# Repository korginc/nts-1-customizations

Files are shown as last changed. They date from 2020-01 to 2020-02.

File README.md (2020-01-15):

# nts-1-customizations

Official repository for hardware customizations of the [Nu:Tekt NTS-1 digital kit](https://www.korg.com/nts_1) programmable synthesizer. 

Make your own custom interface using reference schematics, CAD and PCB data, and libraries for the Arduino IDE.

## Repo Content

* _Arduino/package_nts1_custom_panels_index.json_: Arduino IDE package Boards Manager package description file
* _Custom_Panel_RevC/_: Content specific to NTS-1 Custom Panel reference board revision C
  * _Arduino/libraries/_: Arduino IDE libraries
  * _Gerber/_: Raw PCB Gerber data output
  * _KiCAD/_: [KiCAD](https://kicad-pcb.org/) project
  * _BOM-mouser.pdf_: Bill of materials with [Mouser](https://www.mouser.com/) part numbers in PDF format
  * _BOM-mouser.xls_: Bill of materials with [Mouser](https://www.mouser.com/) part numbers in XLS format (can be uploaded directly to cart)
  * _Gerber\_reference.pdf_: PCB trace and masks visual reference in PDF format
  * _mount\_diagram.pdf_: Part placement visual reference in PDF format
  * _schematic.pdf_: Circuit diagram in PDF format

## Assembly/Programming

Refer to the [companion web site](https://korginc.github.io/nts-1-customizations) for assembly/programming instructions, examples and further reference.

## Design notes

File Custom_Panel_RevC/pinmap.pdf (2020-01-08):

NTS-1 Custom Panel

Arduino IDE pin mapping

| CN7 outside | | CN7 inside | | CN10 inside | | CN10 outside
pin | STM32 | arduino | pin | STM32 | arduino | pin | STM32 | arduino | pin | STM32 | arduino
1 | PC_10 | D16 | 2 | PC_11 | D31 | 1 | PC_9 | D33 | 2 | PC_8 | D34
3 | PC_12 | D17 | 4 | PD_2 | D32 | 3 | PB_8 | D15/I2C SCL | 4 | PC_6 | D35
5 | 3.3V | | 6 | x | | 5 | PB_9 | D14/I2C SDA | 6 | PC_5 | D36/A12
7 | BOOT0 | | 8 | GND | | 7 | 3.3Vref | | 8 | x
9 | PF_6 | D18 | 10 | x | | 9 | GND | | 10 | x
11 | PF_7 | D19 | 12 | 3.3V | | 11 | PA_5 | D13/A9/SPI SCK | 12 | PA_12 | D37
13 | PA_13 | D20 (used for SWD) | 14 | NRST | | 13 | PA_6 | D12/A8/SPI MISO | 14 | PA_11 | D38
15 | PA_14 | D21 (used for SWD) | 16 | 3.3V | | 15 | PA_7 | D11/A7/SPI MOSI | 16 | PB_12 | D39 (used for NTS-1)
17 | PA_15 | D22 | 18 | x | | 17 | PB_6 | D10 | 18 | PB_11 | D40
19 | GND | | 20 | GND | | 19 | PC_7 | D9 | 20 | GND
21 | PB_7 | D23 | 22 | GND | | 21 | PA_9 | D8 | 22 | PB_2 | D41
23 | PC_13 | D24 | 24 | x | | 23 | PA_8 | D7 | 24 | PB_1 | D42/A6
25 | PC_14 | D25 | 26 | x | | 25 | PB_10 | D6 | 26 | PB_15 | D43 (used for NTS-1)
27 | PC_15 | D26 | 28 | PA_0 | D49/A0 | 27 | PB_4 | D5 | 28 | PB_14 | D44 (used for NTS-1)
29 | PF_0 | D27 | 30 | PA_1 | D50/A1 | 29 | PB_5 | D4 | 30 | PB_13 | D45 (used for NTS-1)
31 | PF_1 | D28 | 32 | PA_4 | D51/A2 | 31 | PB_3 | D3 | 32 | x
33 | 3.3V | | 34 | PB_0 | D52/A3 | 33 | PA_10 | D2 | 34 | PC_4 | D46/A13
35 | PC_2 | D29/A10 | 36 | PC_1 | D53/A4 | 35 | PA_2 | D1/TX(used for CN3) | 36 | PF_5 | D47
37 | PC_3 | D30/A11 | 38 | PC_0 | D54/A5 | 37 | PA_3 | D0/RX(used for CN3) | 38 | PF_4 | D48

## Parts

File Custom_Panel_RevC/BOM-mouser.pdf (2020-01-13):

Mfr Part Number (Input) | Manufacturer Part Number | Mouser Part Number | Manufacturer Name | Description | Quantity 1 | Datasheet URL | Unit Price
RC0603JR-070RL | RC0603JR-070RL | 603-RC0603JR-070RL | Yageo | Thick Film Resistors - SMD Thick Film Resistors - SMD ZERO OHM JUMPER | 1 | https://www.mouser.com/datasheet/2/447/PYu-RC_Group_51_RoHS_L_10-1664068.pdf | $0.10
RC0603JR-0733RL | RC0603JR-0733RL | 603-RC0603JR-0733RL | Yageo | Thick Film Resistors - SMD Thick Film Resistors - SMD 33 OHM 5% | 1 | https://www.mouser.com/datasheet/2/447/PYu-RC_Group_51_RoHS_L_10-1664068.pdf | $0.10
RC0603JR-0747RL | RC0603JR-0747RL | 603-RC0603JR-0747RL | Yageo | Thick Film Resistors - SMD Thick Film Resistors - SMD 47 OHM 5% | 4 | https://www.mouser.com/datasheet/2/447/PYu-RC_Group_51_RoHS_L_10-1664068.pdf | $0.10
RC0603JR-07220RL | RC0603JR-07220RL | 603-RC0603JR-07220RL | Yageo | Thick Film Resistors - SMD Thick Film Resistors - SMD 220 OHM 5% | 8 | https://www.mouser.com/datasheet/2/447/PYu-RC_Group_51_RoHS_L_10-1664068.pdf | $0.10
RC0603JR-07100KL | RC0603JR-07100KL | 603-RC0603JR-07100KL | Yageo | Thick Film Resistors - SMD Thick Film Resistors - SMD 100K OHM 5% | 1 | https://www.mouser.com/datasheet/2/447/PYu-RC_Group_51_RoHS_L_10-1664068.pdf | $0.10
RC0603JR-0710KL | RC0603JR-0710KL | 603-RC0603JR-0710KL | Yageo | Thick Film Resistors - SMD Thick Film Resistors - SMD 10K OHM 5% | 4 | https://www.mouser.com/datasheet/2/447/PYu-RC_Group_51_RoHS_L_10-1664068.pdf | $0.10
RC0603JR-071KL | RC0603JR-071KL | 603-RC0603JR-071KL | Yageo | Thick Film Resistors - SMD Thick Film Resistors - SMD 1K OHM 5% | 2 | https://www.mouser.com/datasheet/2/447/PYu-RC_Group_51_RoHS_L_10-1664068.pdf | $0.10
RC0603JR-0747KL | RC0603JR-0747KL | 603-RC0603JR-0747KL | Yageo | Thick Film Resistors - SMD Thick Film Resistors - SMD 47K OHM 5% | 1 | https://www.mouser.com/datasheet/2/447/PYu-RC_Group_51_RoHS_L_10-1664068.pdf | $0.10
C0603C104K4REC | C0603C104K4RECTU | 80-C0603C104K4RECTU | KEMET | Multilayer Ceramic Capacitors MLCC - SMD/SMT Multilayer Ceramic Capacitors MLCC - SMD/SMT 16V 0.1uF 0603 X7R 10% | 4 | https://www.mouser.com/datasheet/2/212/KEM_C1090_X7R_ESD-1103328.pdf | $0.11
C0603C102K4REC | C0603C102K4RECAUTO | 80-C0603C102K4RECAUT | KEMET | Multilayer Ceramic Capacitors MLCC - SMD/SMT Multilayer Ceramic Capacitors MLCC - SMD/SMT 16V 1000pF 0603 X7R 10% AEC-Q200 | 2 | https://www.mouser.com/datasheet/2/212/KEM_C1090_X7R_ESD-1103328.pdf | $0.15
C0805C105K4PAC | C0805C105K4PAC | 80-C0805C105K4PAC | KEMET | Multilayer Ceramic Capacitors MLCC - SMD/SMT Multilayer Ceramic Capacitors MLCC - SMD/SMT 16V 1uF X5R 0805 10% | 1 | https://www.mouser.com/datasheet/2/212/KEM_C1006_X5R_SMD-1103249.pdf | $1.05
1-87215-9 | 1-87215-9 | 571-1-87215-9 | TE Connectivity | Headers & Wire Housings Headers & Wire Housings 38 MODII HDR DRST UNSHRD .100 | 2 | https://www.mouser.com/datasheet/2/418/NG_CD_87215_J4-642383.pdf | $13.56
215299-0 | 215299-2 | 571-215299-2 | TE Connectivity | Headers & Wire Housings Headers & Wire Housings 1X02P RCPT HV-100 TE | 1 | https://www.mouser.com/datasheet/2/418/NG_CD_215299_E-1247332.pdf | $0.64
215299-6 | 215299-6 | 571-215299-6 | TE Connectivity | Headers & Wire Housings Headers & Wire Housings 6P RECPT VERT HV-100 | 1 | https://www.mouser.com/datasheet/2/418/NG_CD_215299_E-1247285.pdf | $1.16
215299-8 | 215299-8 | 571-215299-8 | TE Connectivity | Headers & Wire Housings Headers & Wire Housings 8P RECPT VERT HV-100 | 2 | https://www.mouser.com/datasheet/2/418/NG_CD_215299_E-1247329.pdf | $1.45
826926-3 | 826926-3 | 571-826926-3 | TE Connectivity | Headers & Wire Housings Headers & Wire Housings 1X03 POS VERT TIN | 2 | https://www.mouser.com/datasheet/2/418/NG_CD_826629_AC-1262378.pdf | $0.27
826926-4 | 826926-4 | 571-826926-4 | TE Connectivity | Headers & Wire Housings Headers & Wire Housings 1X04 POS VERT TIN | 1 | https://www.mouser.com/datasheet/2/418/NG_CD_826629_AC-673695.pdf | $0.32
XJ8B-0711 | XJ8B-0211 | 653-XJ8B-0211 | Omron | Headers & Wire Housings Headers & Wire Housings Sensor I/O Connector | 2 | https://www.mouser.com/datasheet/2/307/en-xg8-1539045.pdf | $0.39
WP7113SRD/J4 | WP7113SRD/J4 | 604-WP7113SRDJ4 | Kingbright | Standard LEDs - Through Hole Standard LEDs - Through Hole 5mm Red LED 640nm | 8 | https://www.mouser.com/datasheet/2/216/WP7113SRD-J4-1114353.pdf | $0.56
RK09K1130A5R | RK09K1130A5R | 688-RK09K1130A5R | ALPS | Potentiometers Potentiometers 10 KOhms 20% | 1 | https://www.mouser.com/catalog/specsheets/alps_alps-s-a0003696969-1.pdf | $0.84
SKRGAAD010 | SKRGAAD010 | 688-SKRGAAD010 | ALPS | Tactile Switches Tactile Switches RND 6.0x4.3mm 100gf | 10 | https://www.mouser.com/catalog/specsheets/alps_alps-s-a0002902225-1.pdf | $0.21
STM32F030R8T6 | STM32F030R8T6 | 511-STM32F030R8T6 | STMicroelectronics | ARM Microcontrollers - MCU ARM Microcontrollers - MCU Value-Line ARM MCU 64kB 48 MHz | 1 | https://www.mouser.com/datasheet/2/389/stm32f030f4-956260.pdf | $1.89
827914-3 | 827914-3 | 571-827914-3 | TE Connectivity | Headers & Wire Housings Headers & Wire Housings 2 POS POST SHUNT | 1 | https://www.mouser.com/datasheet/2/418/NG_SS_108-37006_D-876462.pdf | $0.43

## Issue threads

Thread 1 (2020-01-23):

NTS-1_CustomPanel.lib is missing

tokuhira, 2020-01-23:
**Is your feature request related to a problem? Please describe.**
"Custom_Panel_RevC / KiCAD / sym-lib-table" refers to "$ {KIPRJMOD} /NTS-1_CustomPanel.lib", but it is not included in the repository.

**Describe the solution you'd like**
Having a symbol table can be very helpful when we try to further customize the board. If it is publicly available, add it to the repository.

 Anyway, thank you very much for the great project. This is the best introduction to making electronic instruments ever.

grajohnt, 2020-02-02:
Echoing this. It would be great to start making modifications, but without these symbols, it's a bit tricky to even get started.

KreoPensas, 2021-11-22:
Still nothing?

fopinski, 2023-02-02:
Push... Would be a shame. Maybe that's why we cannot find custom pannels at all?

matozoid, 2023-02-11:
Since this repository was made, nothing happened. No code was added, no issues were addressed, it is completely abandoned. Maybe someone within Korg can be contacted directly about this.

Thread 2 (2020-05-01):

A Simple Introduction Please

scotus-49, 2020-05-01:
Do you have anywhere information for the average Arduino user to get started with customizing the NTS-1? Something using readily available components for simple experiments? Your examples seem to assume a high professional level of soldering and programming.

Has anyone outside of Korg actually done this? I can at present find no sign on the internet of anyone managing to do any hardware customization. It"s a great idea, but how does the average person get started?

samjkent, 2020-05-04:
I've not used it but had a browse of the source as it sounded cool (I've not got an NTS-1, and have no affiliation with Korg or this project)

To communicate in an Arduino environment you can use this library from the examples folder, which abstracts the communication layer to some nice functions and events [1]

It looks like the comms layer (using SPI) is only implemented for STM32 at the moment, so incompatible with a traditional atmega arduino (uno, mega etc.), [STM32duino](https://github.com/stm32duino) / platform.io are probably the simplest ways to get started

If you wanted to use an official Arduino, the interface header file is fairly generic [2] , so you'd need to implement `nts1_iface.c` setting up SPI using Arduino abstractions / whatever processor is on your dev board

[1] https://github.com/korginc/nts-1-customizations/tree/master/Custom_Panel_RevC/Arduino/libraries/NTS-1

[2] https://github.com/korginc/nts-1-customizations/blob/master/Custom_Panel_RevC/Arduino/variants/NTS1_REF_CP_REVC/nts1_iface.

[3] https://github.com/korginc/nts-1-customizations/blob/master/Custom_Panel_RevC/Arduino/variants/NTS1_REF_CP_REVC/nts1_iface.c

scotus-49, 2020-05-05:
@samjkent
Thanks for the info. I had not dug so deep into the Korg information, and had not come across this.
I am based in Berlin, Germany, where none of my local maker  suppliers  (ie Conrad) have SMT32 boards, but traditional arduinos are available over the counter.
I will have a look into the code to see whether I can do something with it.
I also have no connection with Korg, but I thought I had heard (unconfirmed) that they had started a firm here in Berlin to do with their Nu:Tekt range of products.
The NTS-1 is quite fun to play with and program, and seems an ideal match for the arduino range of micro-controllers to extend its' functions.
I usually code in Python, but I'll give this a try.

eudes, 2020-08-07:
Hey @scotus-49,

I'm working on understanding the STM32 library provided here and possibly building one for the ESP32. I'm also documenting the analysis, which might help you out a bit. It's not yet complete and I don't have any working code, but I go quite a bit into detail about how this code works. I also plan on updating it frequently over the next few days as I progress.

Here's the repo:
https://github.com/eudes/korg-nts1-esp32

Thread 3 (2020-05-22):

Gerber Top Outline showing QR code to a broken URL

hinzvc, 2020-05-22:
The gerber file name  "NTS-1_CustomPanel.gto" shows a QR code that points to the following broken URL:  https://www.korg.com/us/products/dj/nts_1/custom_panel/

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

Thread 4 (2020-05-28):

Sending pitch bend event from custom panel

centrevillage, 2020-05-28:
I want to send a pitch bend event from a custom panel, but the API doesn't exist.

Is it possible to add that API?

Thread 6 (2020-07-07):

Having trouble communicating with TFT screen

matrix12x, 2020-07-07:
I am trying to use a TFT screen with the NTS-1 Custom Control surface and get compile errors on any library I try and use.

I have definitely gotten this TFT to work with an Arduino Uno. for example, I select File>Example>ADAFRUIT TFTLCD Library>graphics test

However, When I set the Arduino IDE to NTS-1 Custom Panels (instead of for example Uno), I get errors on any TFT library.
I can't seem to figure out what to use instead of something like: defined(__AVR_ATmega328P__)  for the STM32.

Any suggestions would be welcome. Also I am requesting Korg put up some sample code for the TFT example they did.

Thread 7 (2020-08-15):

Integrate Espressif ESP32 implementation of the library

eudes, 2020-08-15:
Hello!

I've been working on an implementation of the NTS-1 C interface for the Espressif ESP32. It needs still needs polishing, but it is mostly working as a feature-complete replacement for the ESP32 IDF framework.

Would there be any interest in merging the implementation into the official repository?

### Some more  context

I started it as a fork of this project, and it reuses most of the code, only diverging for the `init` and `idle` phases, and in the way it communicates with the MCU's SPI peripheral. In the process of separating the STM32-specific code from the rest, I managed to carve out a clear API on which to base my framework-dependent implementation. This API, I think, provides a great deal of support anyone trying to implement the library for other frameworks/MCUs, as it provides a clear division between those parts of the code that are specific to an architecture, and those that aren't and can be reused.

I'm no expert in embedded programming, or C for that matter, so I'll be more than open to any suggestions or advice that might arise in the process.

As I said, I just finished making it work and I'll be polishing kinks and testing it more thoroughly, but I thought, given that there's not much activity in this repo, that it would be good to ask early.

### The code
I'm working on it at https://github.com/eudes/nts-1-customizations. This is the [ESP-specific code](https://github.com/eudes/nts-1-customizations/blob/master/Custom_Panel_RevC/Arduino/variants/NTS1_REF_CP_REVC/esp32/nts1_esp32.c). The original STM32 code has many added comments there, but the actual code is the same.

I also created a `library.json` file to make it easier to use with platformio.

There's a sample project that uses the implementation here: https://github.com/eudes/korg-nts1-esp32. This one is more liable to change over time as I'm using it for testing and documenting the process. It might also be nice, for people trying to port the library to other platforms, to have some of the details there incorporated into the official documentation. I know there's a mention in this repo of "more details about the communication protocol will be released at a later date", but in the meantime it could serve as a helping hand.

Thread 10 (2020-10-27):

Request an "blinky-led" example for completed boards.

jw-smaal, 2020-10-27:
I have just finished soldering my NTS-1 custom panel which I consider quite an achievement with all the tiny SMD components.   I am super excited that Korg has made the design open and can't wait to get involved more.

I'd like to request a way to quickly do a basic test on the completed board; like a "blinky" led test without requiring the whole Arduino toolchain.  Basically a binary I can just drop on the STM32 Nucleo ST-LINK "removable drive"  and will case the leds to light up, read the switch status and read the potmeter.  Ouput to the serial.   Then I at least know the board is functional to start with.

I could not find ready to upload binaries for a quick test.

Thanks a lot for this great project from Korg!

jw-smaal, 2020-10-27:
I managed to use the MBED Studio MBED.  Baremetal example on MBED OS 5.15.5  with a NUCLEO-64 (STM32F030) target.    With the Reset jumper set to Debug MODE  I could at least create a basic program to light up the led's read the potmeter, read the switches etc...   Next step check the communications with the main NTS-1 board.

Closed 2020-10-29.

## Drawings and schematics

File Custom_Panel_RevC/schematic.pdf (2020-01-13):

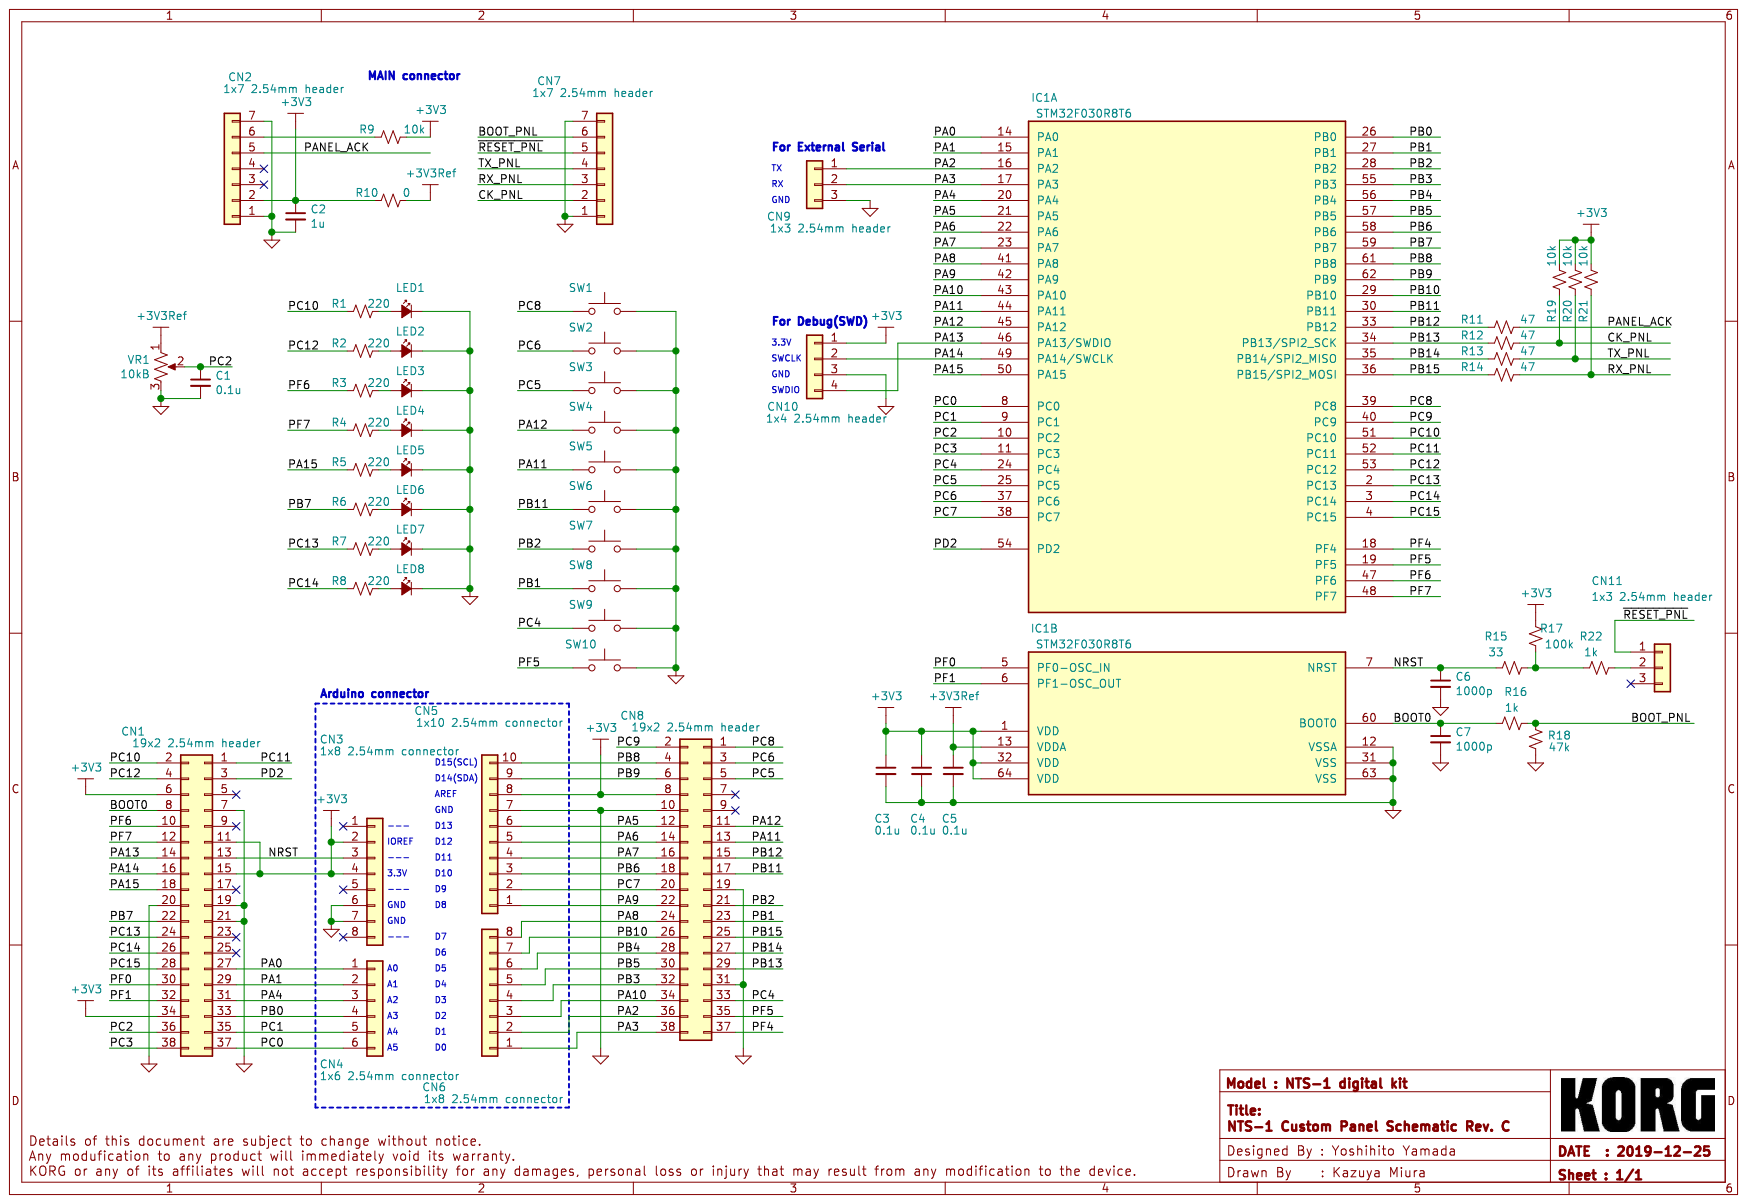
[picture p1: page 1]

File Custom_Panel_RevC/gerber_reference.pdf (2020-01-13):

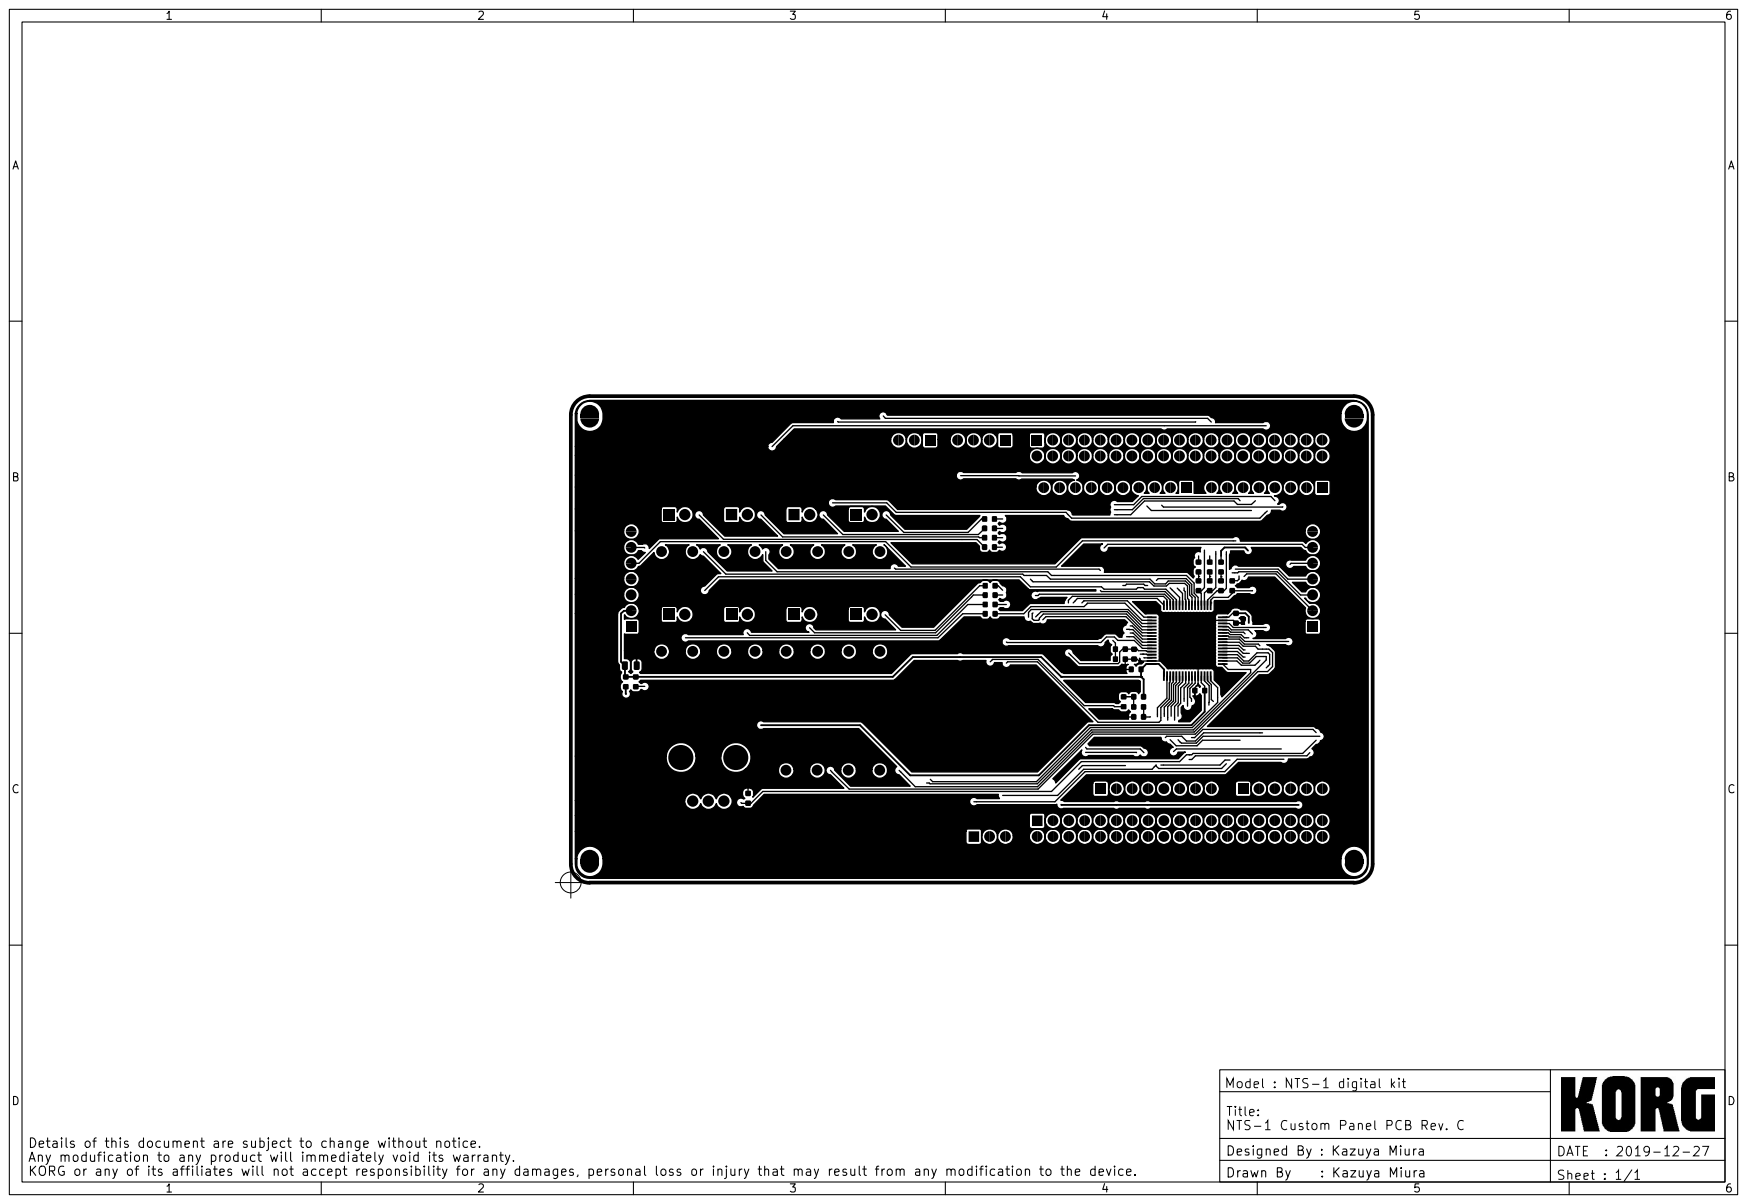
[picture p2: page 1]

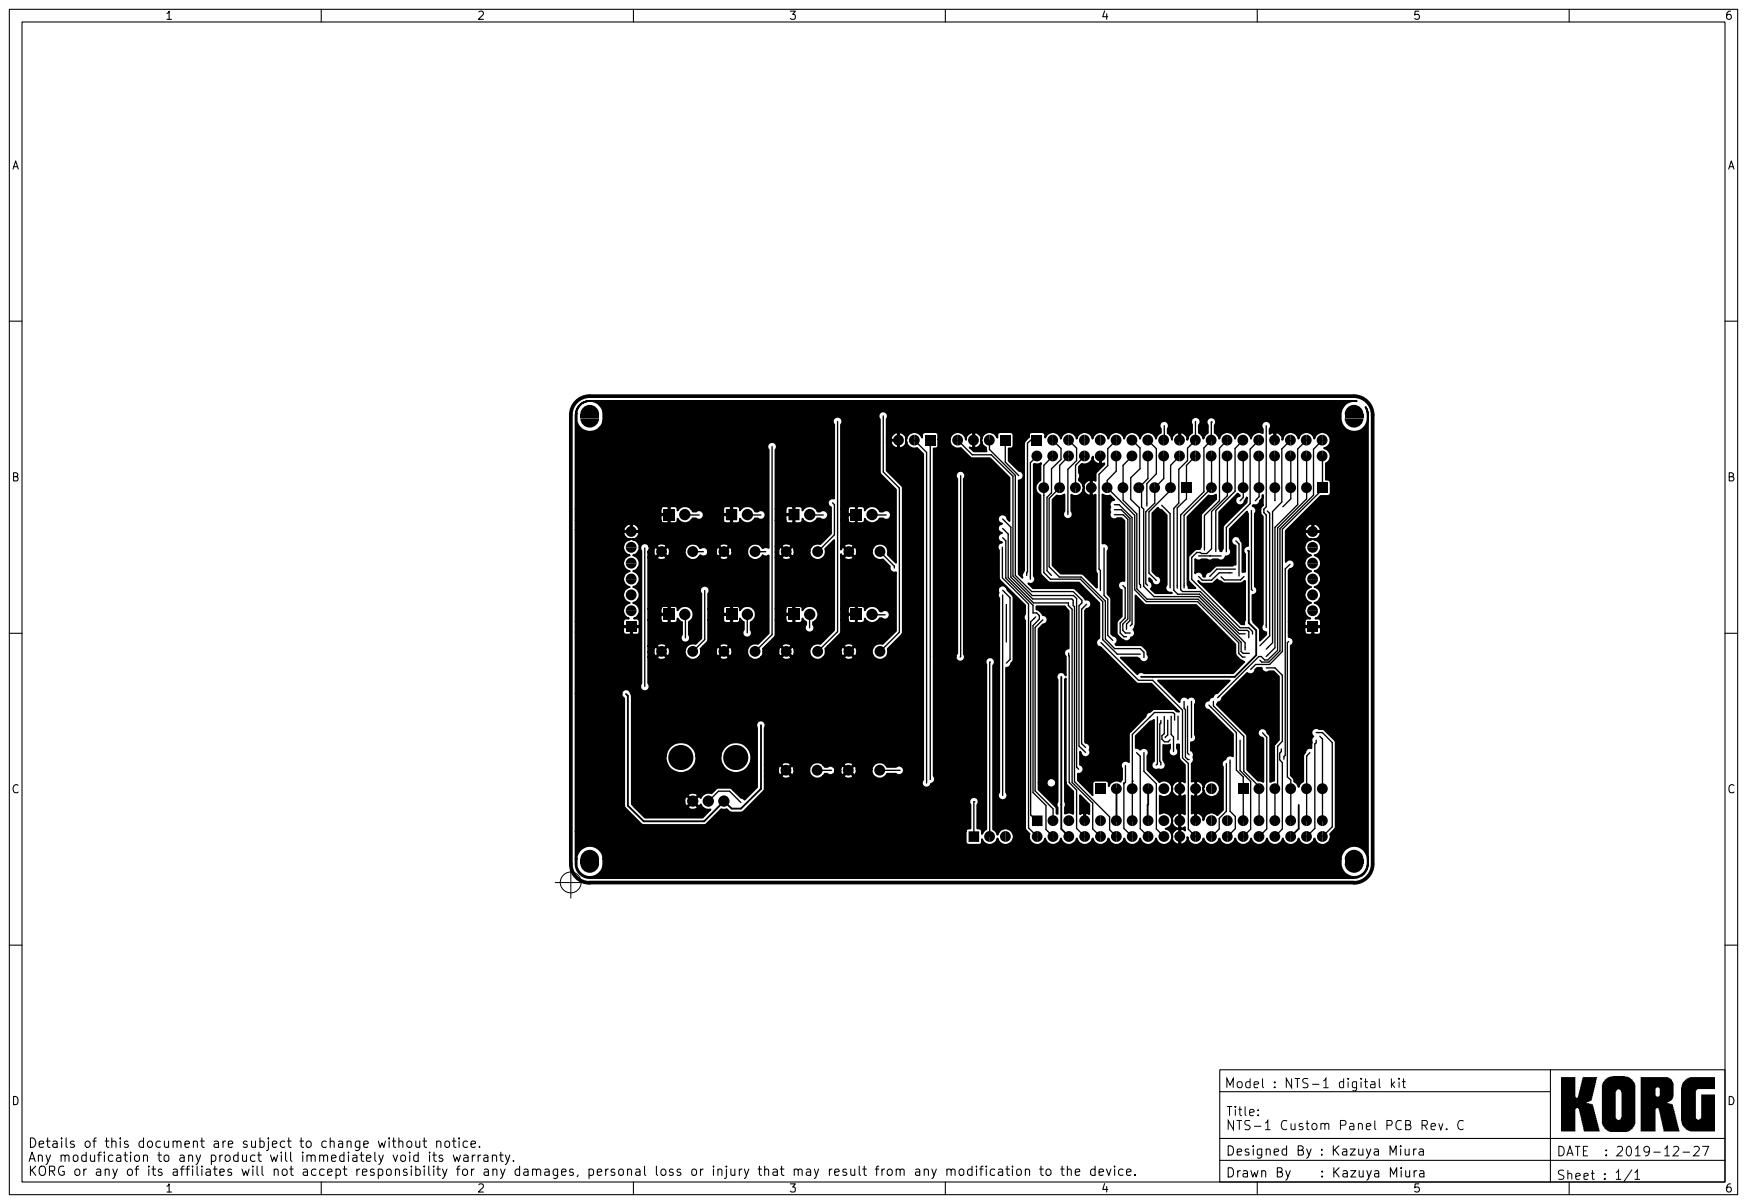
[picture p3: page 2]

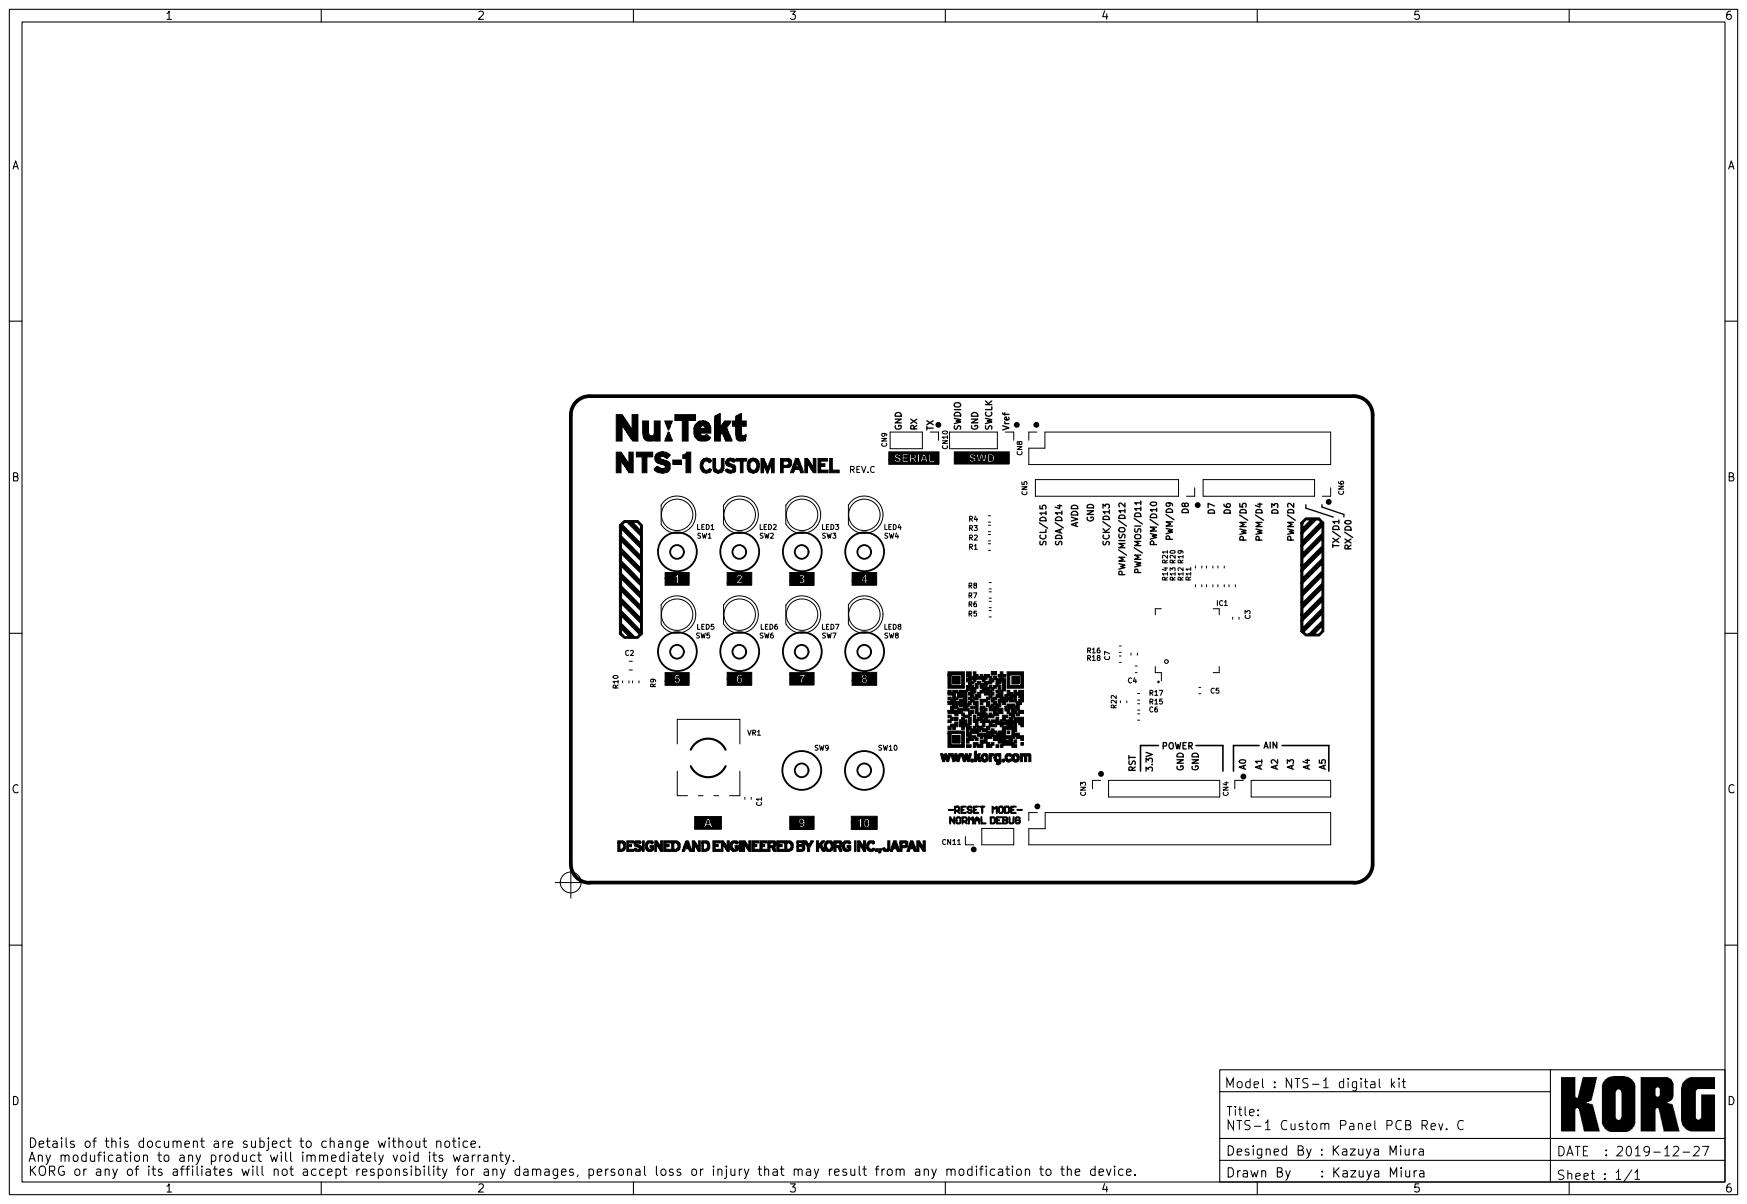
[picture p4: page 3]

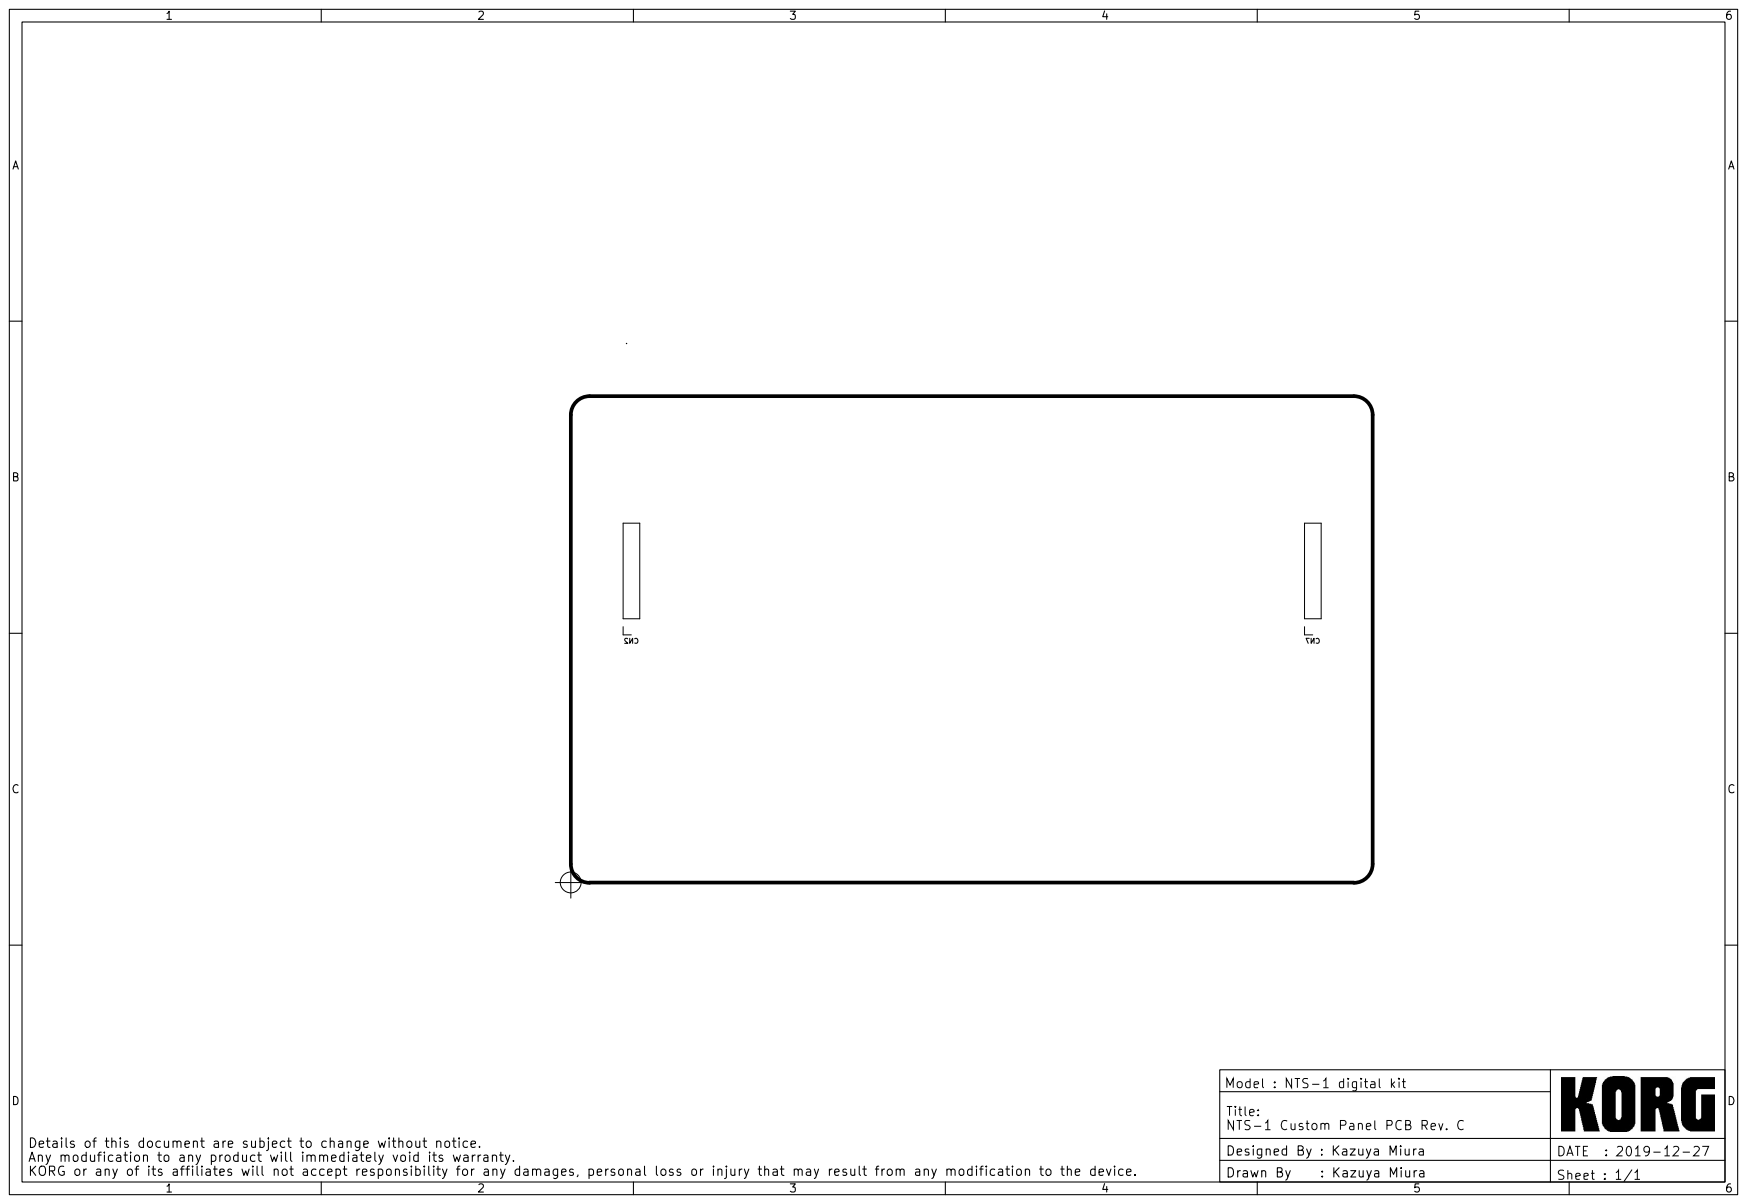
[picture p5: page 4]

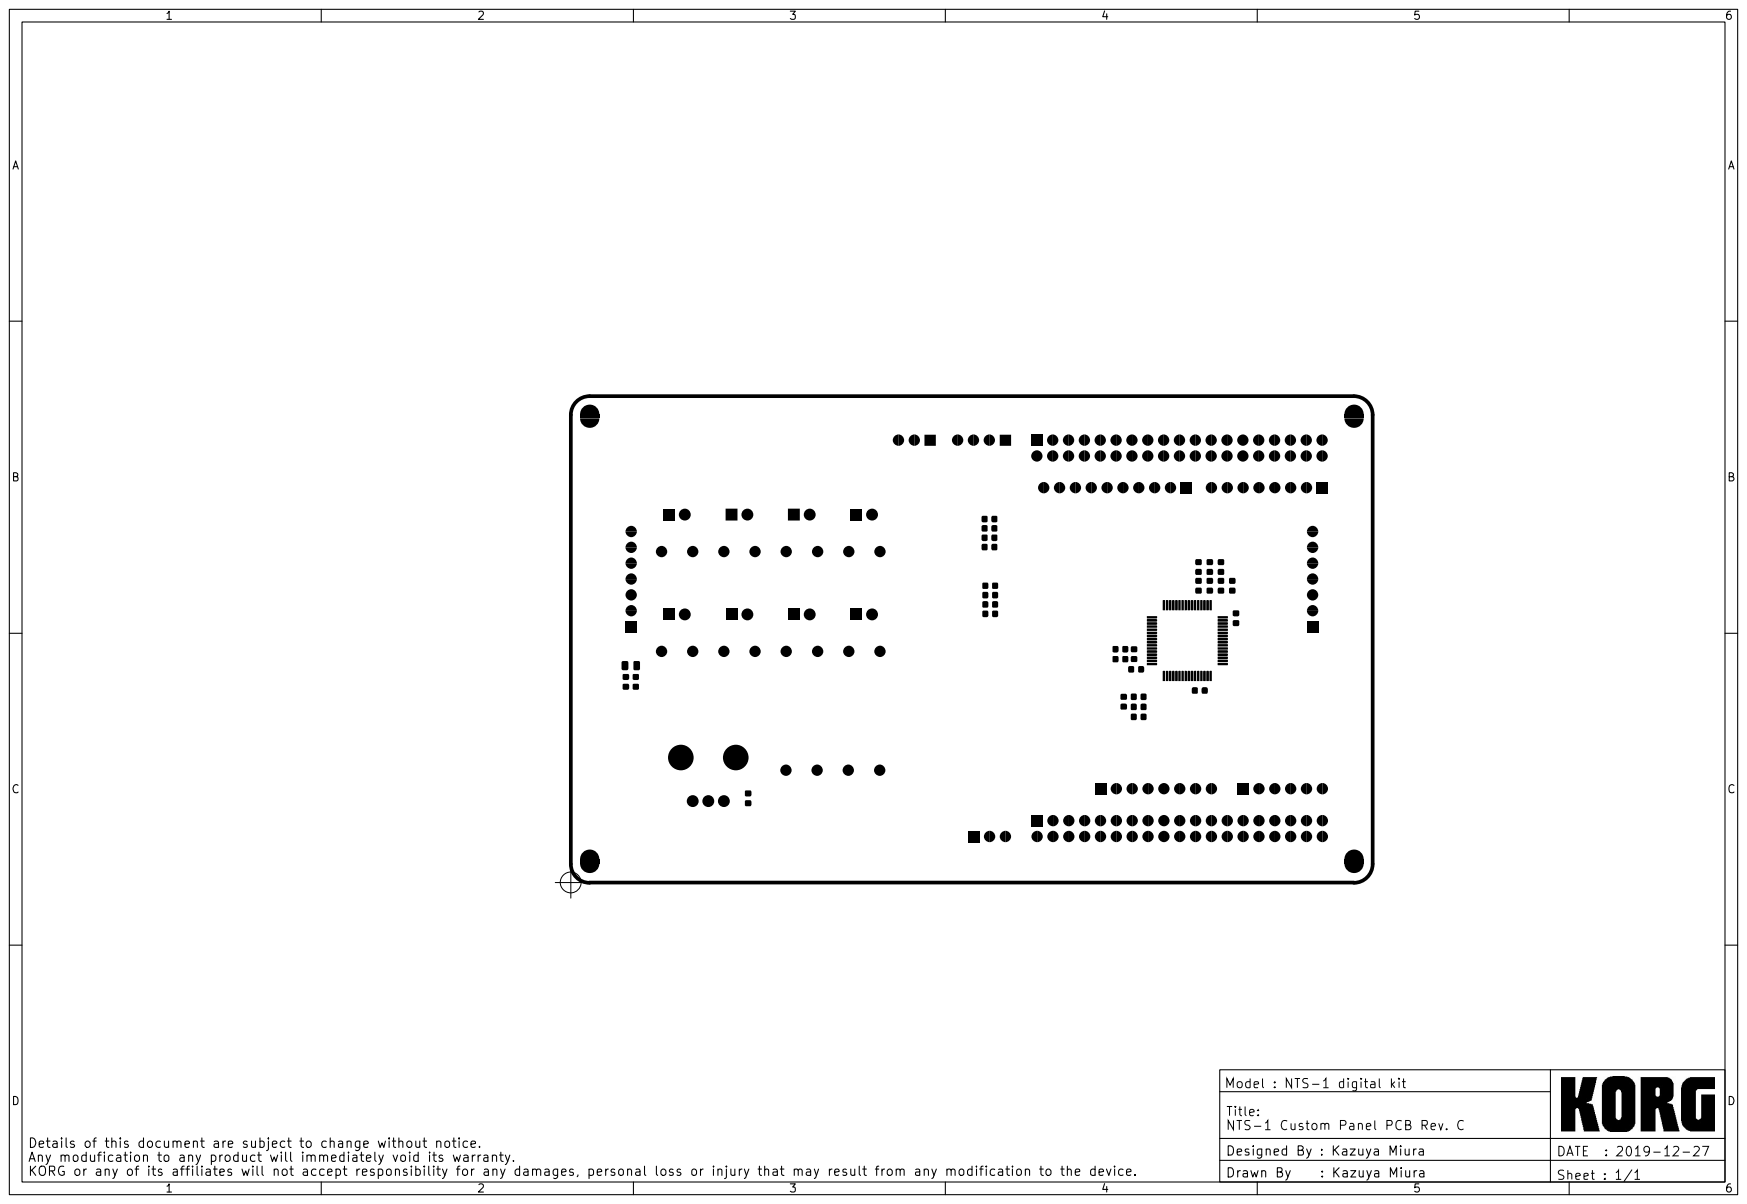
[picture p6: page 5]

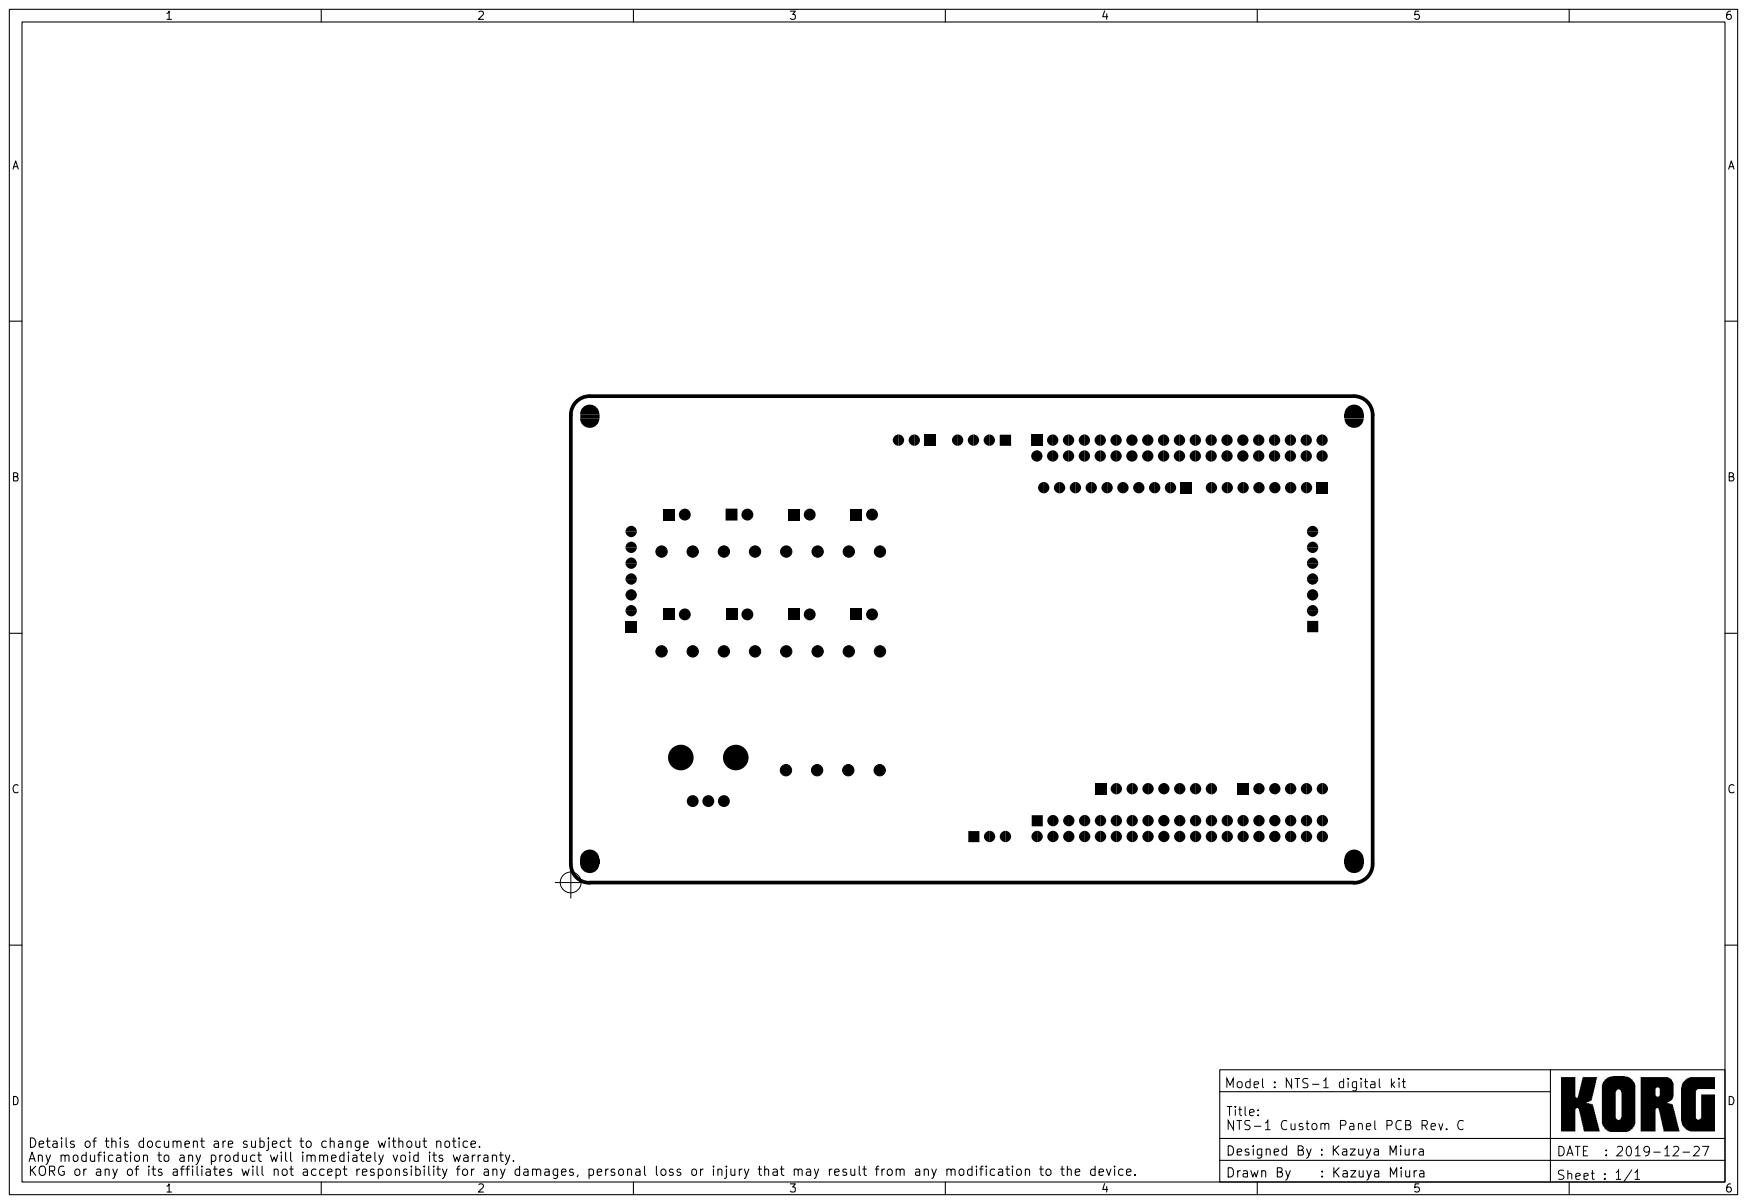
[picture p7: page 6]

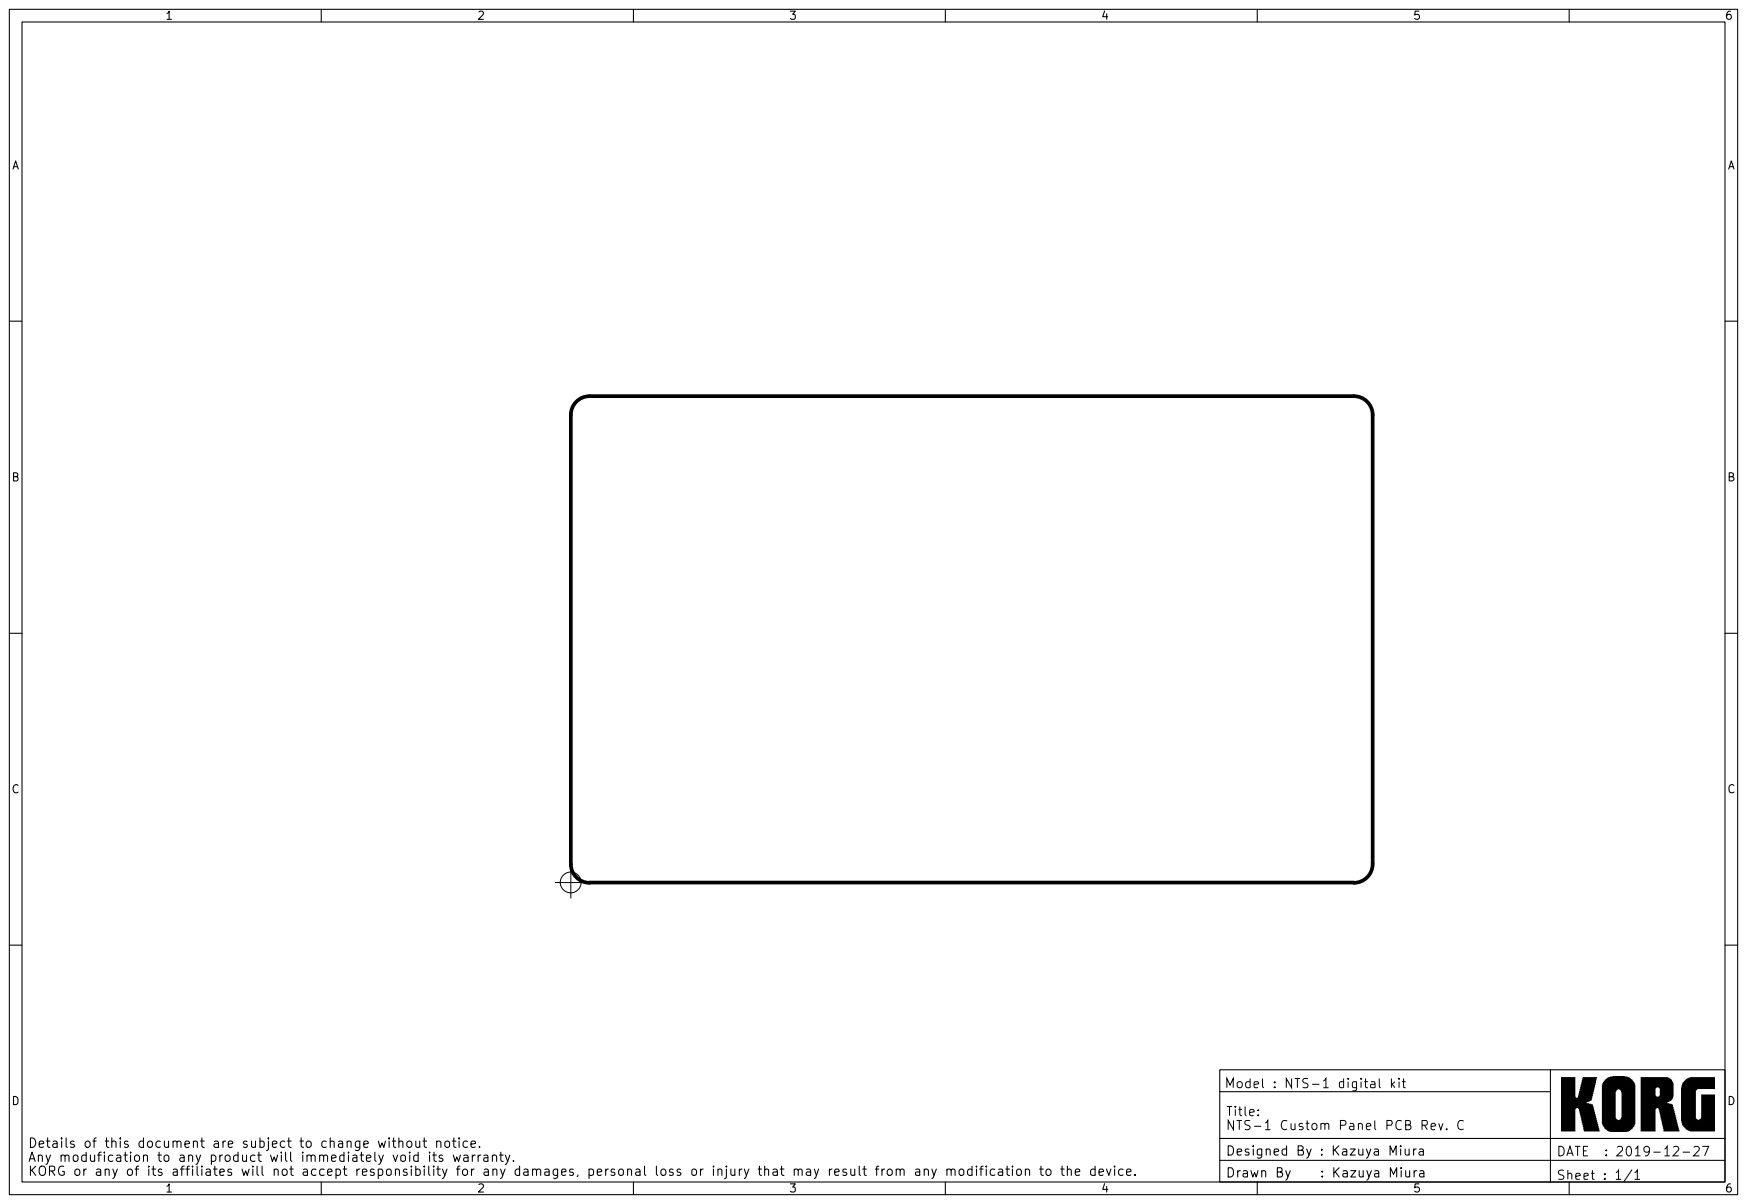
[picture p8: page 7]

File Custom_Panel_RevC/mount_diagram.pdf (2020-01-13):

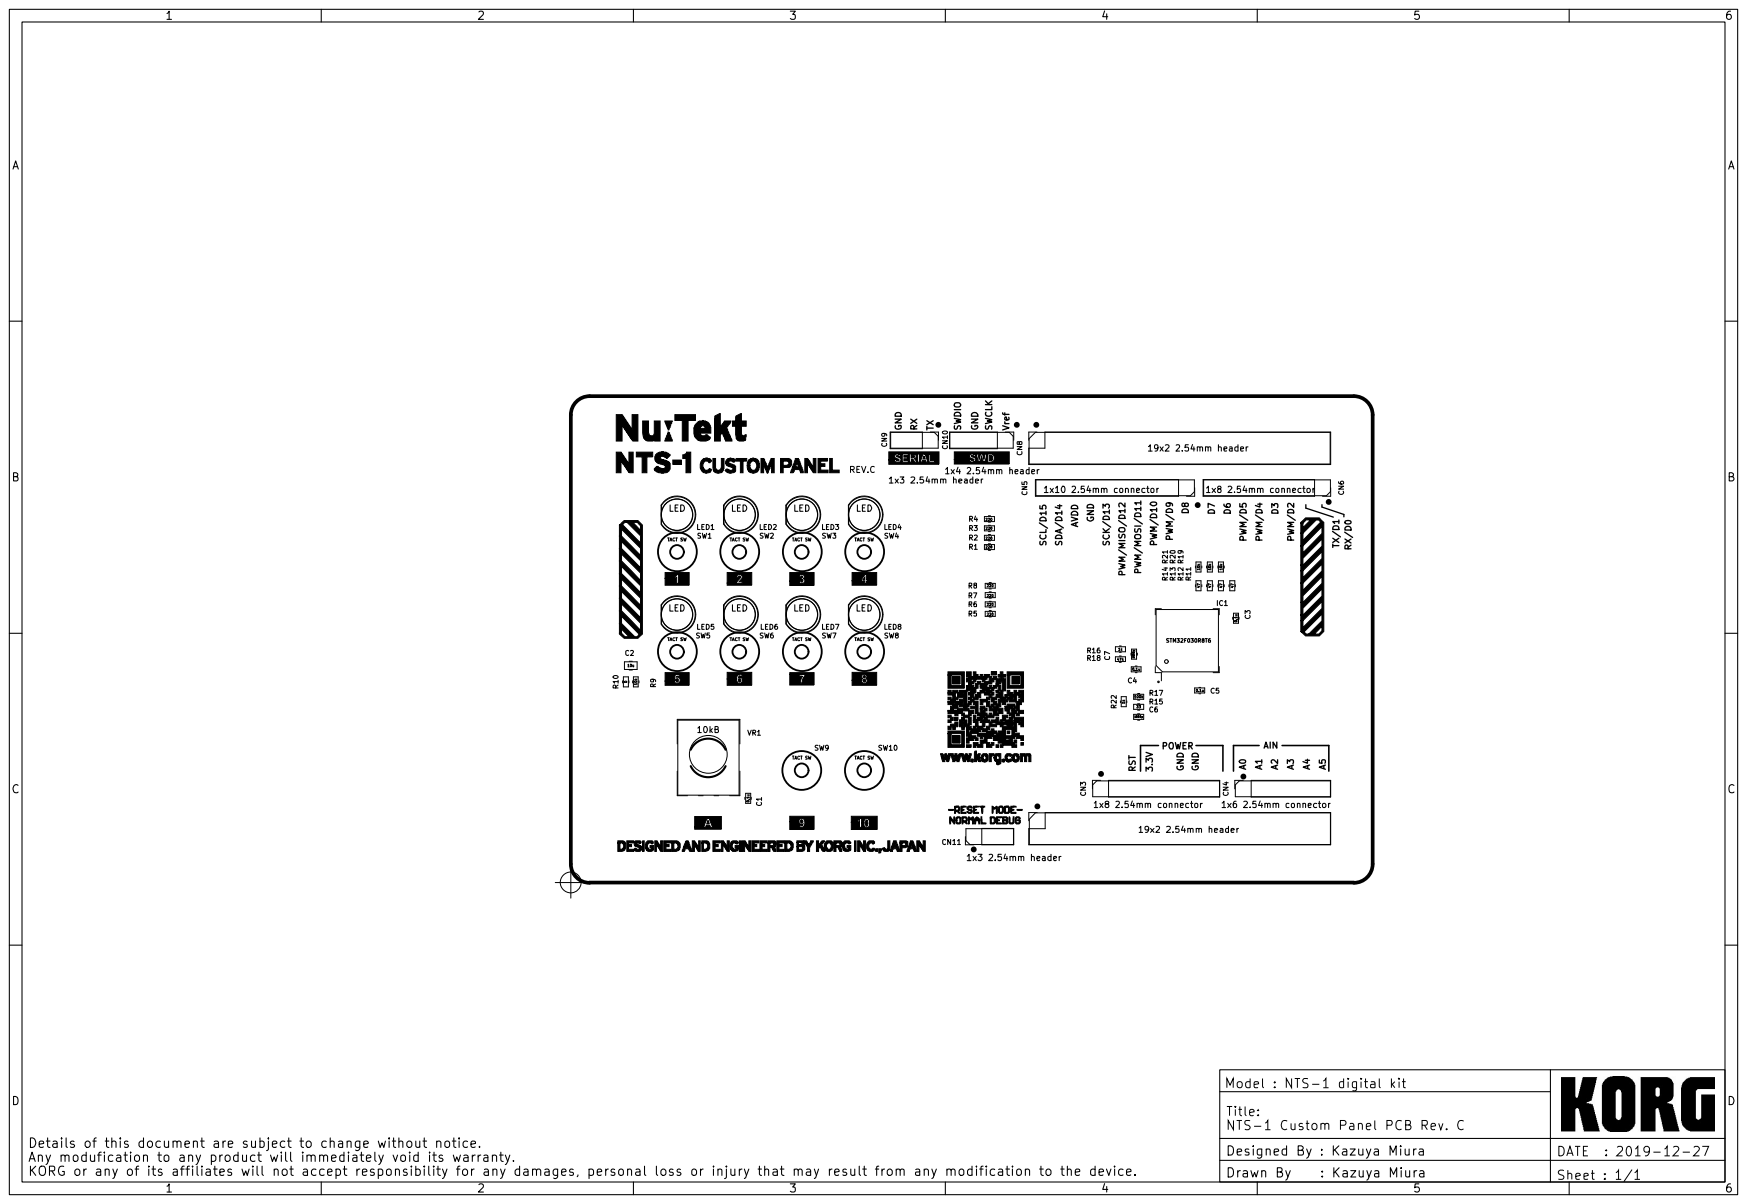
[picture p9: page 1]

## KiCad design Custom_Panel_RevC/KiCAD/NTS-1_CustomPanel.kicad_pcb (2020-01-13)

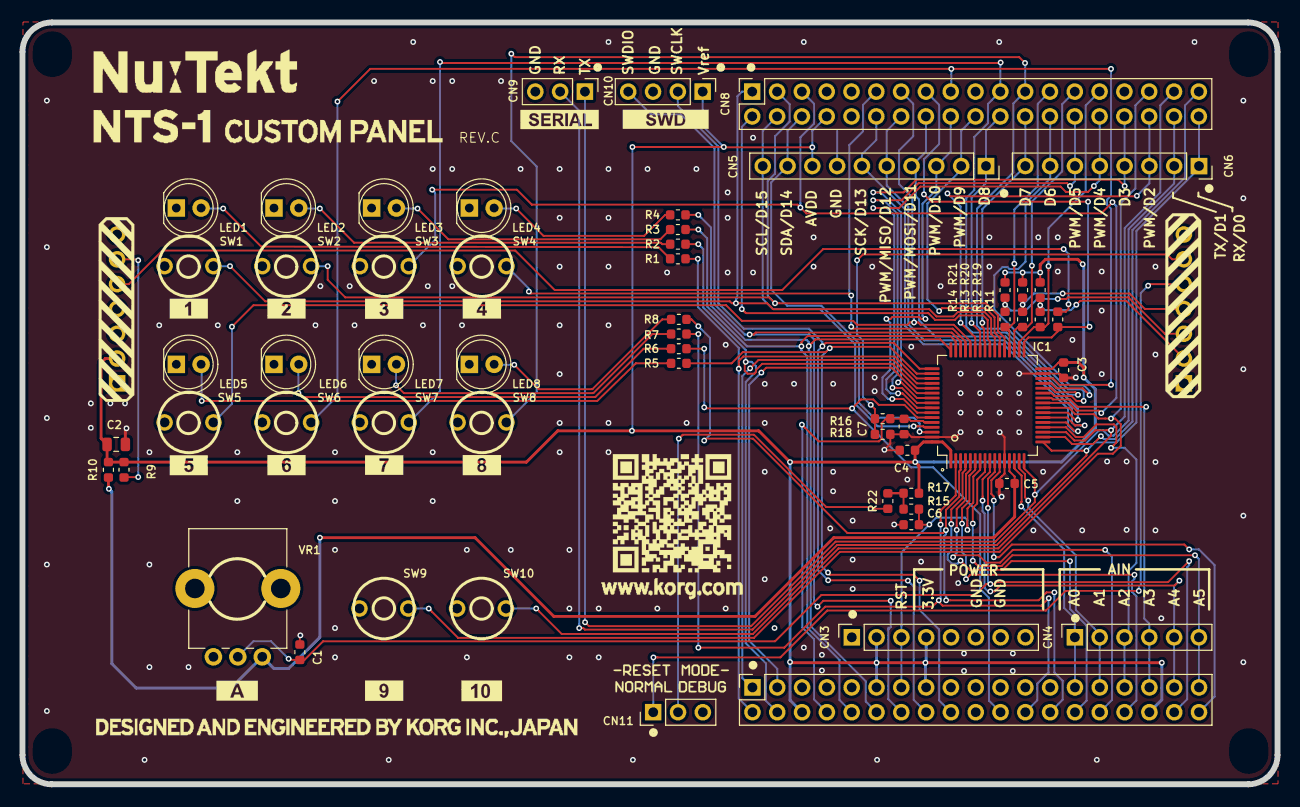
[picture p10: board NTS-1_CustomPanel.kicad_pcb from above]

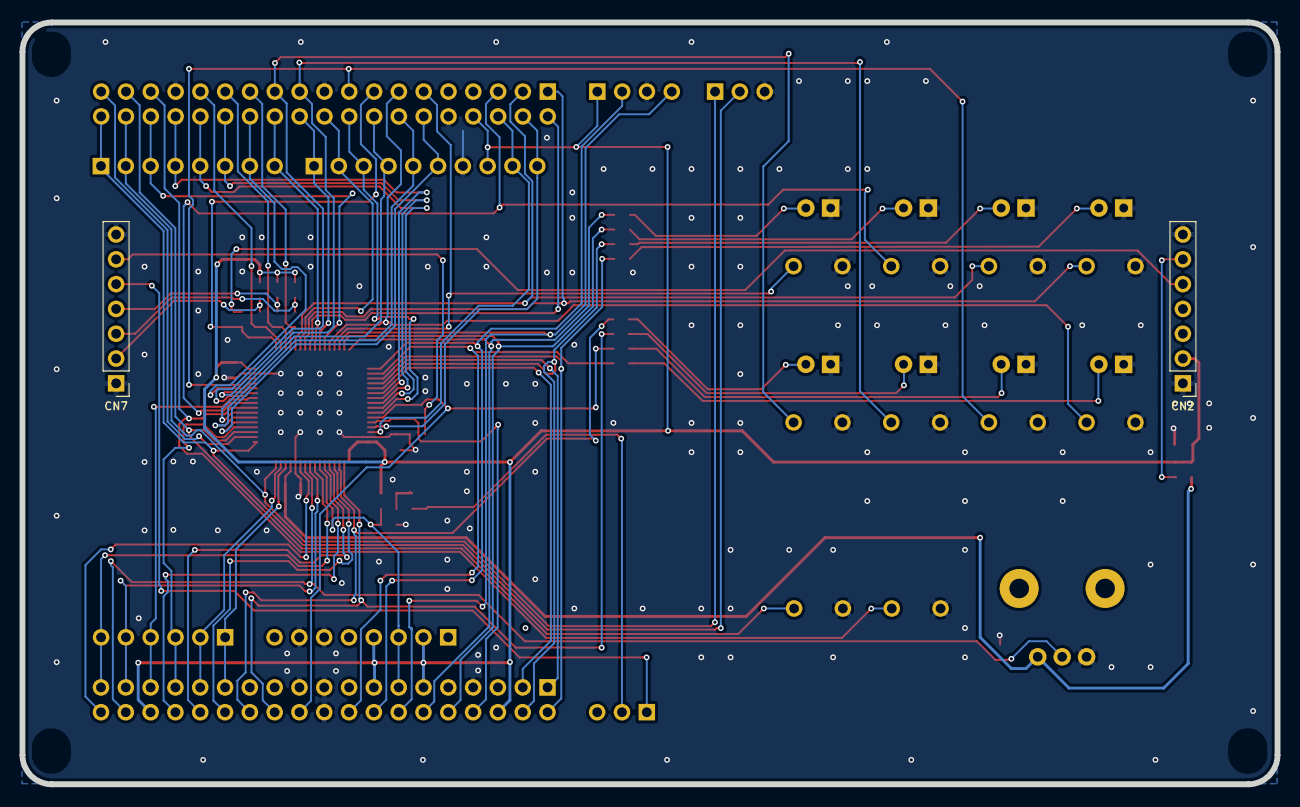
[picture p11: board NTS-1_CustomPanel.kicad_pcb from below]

Board: 2 copper layers, 128.5 x 78.0 mm, 60 parts (2 on the bottom side), 77 nets.

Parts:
C1, C3, C4, C5: 0.1u; C_0603_1608Metric
C2: 10u; C_0805_2012Metric
C6, C7: 1000p; C_0603_1608Metric
CN1, CN8: 19x2 2.54mm header; PinSocket_2x19_P2.54mm_Vertical
CN2, CN7: 1x7 2.54mm header; PinHeader_1x07_P2.54mm_Vertical
CN3, CN6: 1x8 2.54mm connector; PinSocket_1x08_P2.54mm_Vertical
CN4: 1x6 2.54mm connector; PinSocket_1x06_P2.54mm_Vertical
CN5: 1x10 2.54mm connector; PinSocket_1x10_P2.54mm_Vertical
CN9, CN11: 1x3 2.54mm header; PinHeader_1x03_P2.54mm_Vertical
CN10: 1x4 2.54mm header; PinHeader_1x04_P2.54mm_Vertical
IC1: STM32F030R8T6; LQFP-64_10x10mm_P0.5mm
LED1, LED2, LED3, LED4, LED5, LED6, LED7, LED8: LED; LED_D5.0mm
R1, R2, R3, R4, R5, R6, R7, R8: 220; R_0603_1608Metric
R9, R19, R20, R21: 10k; R_0603_1608Metric
R10: 0; R_0603_1608Metric
R11, R12, R13, R14: 47; R_0603_1608Metric
R15: 33; R_0603_1608Metric
R16, R22: 1k; R_0603_1608Metric
R17: 100k; R_0603_1608Metric
R18: 47k; R_0603_1608Metric
SW1, SW2, SW3, SW4, SW5, SW6, SW7, SW8, SW9, SW10: TACT SW; SW_Tactile_SKRH
VR1: 10kB; Potentiometer_Alps_RK09K_Single_Vertical

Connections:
+3V3: C2.1, C3.1, C4.1, CN1.6, CN1.11, CN1.15, CN1.34, CN2.2, CN3.2, CN3.4, CN5.8, CN8.8, CN10.1, IC1.1, IC1.32, IC1.64, R9.1, R10.2, R17.1, R19.1, R20.1, R21.1
+3V3Ref: C5.1, IC1.13, R10.1, VR1.1
/BOOT0: C7.1, CN1.8, IC1.60, R16.2
/BOOT_PNL: CN7.6, R16.1, R18.1
/CK_PNL: CN7.2, R12.1, R19.2
/NRST: C6.1, CN1.13, CN3.3, IC1.7, R15.2
/PA0: CN1.27, CN4.1, IC1.14
/PA1: CN1.29, CN4.2, IC1.15
/PA2: CN6.2, CN8.36, CN9.1, IC1.16
/PA3: CN6.1, CN8.38, CN9.2, IC1.17
/PA4: CN1.31, CN4.3, IC1.20
/PA5: CN5.6, CN8.12, IC1.21
/PA6: CN5.5, CN8.14, IC1.22
/PA7: CN5.4, CN8.16, IC1.23
/PA8: CN6.8, CN8.24, IC1.41
/PA9: CN5.1, CN8.22, IC1.42
/PA10: CN6.3, CN8.34, IC1.43
/PA11: CN8.13, IC1.44, SW5.1
/PA12: CN8.11, IC1.45, SW4.1
/PA13: CN1.14, CN10.4, IC1.46
/PA14: CN1.16, CN10.2, IC1.49
/PA15: CN1.18, IC1.50, R5.2
/PANEL_ACK: CN2.5, R11.1
/PB0: CN1.33, CN4.4, IC1.26
/PB1: CN8.23, IC1.27, SW8.1
/PB2: CN8.21, IC1.28, SW7.1
/PB3: CN6.4, CN8.32, IC1.55
/PB4: CN6.6, CN8.28, IC1.56
/PB5: CN6.5, CN8.30, IC1.57
/PB6: CN5.3, CN8.18, IC1.58
/PB7: CN1.22, IC1.59, R6.2
/PB8: CN5.10, CN8.4, IC1.61
/PB9: CN5.9, CN8.6, IC1.62
/PB10: CN6.7, CN8.26, IC1.29
/PB11: CN8.17, IC1.30, SW6.1
/PB12: CN8.15, IC1.33, R11.2
/PB13: CN8.29, IC1.34, R12.2
/PB14: CN8.27, IC1.35, R13.2
/PB15: CN8.25, IC1.36, R14.2
/PC0: CN1.37, CN4.6, IC1.8
/PC1: CN1.35, CN4.5, IC1.9
/PC2: C1.1, CN1.36, IC1.10, VR1.2
/PC3: CN1.38, IC1.11
/PC4: CN8.33, IC1.24, SW9.1
/PC5: CN8.5, IC1.25, SW3.1
/PC6: CN8.3, IC1.37, SW2.1
/PC7: CN5.2, CN8.20, IC1.38
/PC8: CN8.1, IC1.39, SW1.1
/PC9: CN8.2, IC1.40
/PC10: CN1.2, IC1.51, R1.2
/PC11: CN1.1, IC1.52
/PC12: CN1.4, IC1.53, R2.2
/PC13: CN1.24, IC1.2, R7.2
/PC14: CN1.26, IC1.3, R8.2
/PC15: CN1.28, IC1.4
/PD2: CN1.3, IC1.54
/PF0: CN1.30, IC1.5
/PF1: CN1.32, IC1.6
/PF4: CN8.37, IC1.18
/PF5: CN8.35, IC1.19, SW10.1
/PF6: CN1.10, IC1.47, R3.2
/PF7: CN1.12, IC1.48, R4.2
/RX_PNL: CN7.3, R14.1, R21.2
/TX_PNL: CN7.4, R13.1, R20.2
/~RESET_PNL: CN7.5, CN11.1
GND: C1.2, C2.2, C3.2, C4.2, C5.2, C6.2, C7.2, CN1.7, CN1.19, CN1.20, CN1.21, CN2.1, CN2.7, CN3.6, CN3.7, CN5.7, CN7.1, CN7.7, CN8.10, CN8.19, CN8.31, CN9.3, CN10.3, IC1.12, IC1.31, IC1.63, LED1.1, LED2.1, LED3.1, LED4.1, LED5.1, LED6.1, LED7.1, LED8.1, R18.2, SW1.2, SW2.2, SW3.2, SW4.2, SW5.2, SW6.2, SW7.2, SW8.2, SW9.2, SW10.2, VR1.3
unnamed: CN2.6, R9.2
unnamed: CN11.2, R22.1
unnamed: LED1.2, R1.1
unnamed: LED2.2, R2.1
unnamed: LED3.2, R3.1
unnamed: LED4.2, R4.1
unnamed: LED5.2, R5.1
unnamed: LED6.2, R6.1
unnamed: LED7.2, R7.1
unnamed: LED8.2, R8.1
unnamed: R15.1, R17.2, R22.2

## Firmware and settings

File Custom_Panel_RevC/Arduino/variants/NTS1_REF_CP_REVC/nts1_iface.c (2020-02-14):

/** 
 * @file nts1_iface.c
 * @brief C API handling communication with the NTS-1 digital kit's main board.
 *
 * Provides initialization of necessary peripherals, handling of low level 
 * protocol details and convenience functions for bidrectional communication
 * with the NTS-1 digital kit's main board via SPI.
 *   
 * BSD 3-Clause License
 *  Copyright (c) 2020, KORG INC.
 *  All rights reserved.
 *  Redistribution and use in source and binary forms, with or without
 *  modification, are permitted provided that the following conditions are met:
 * * Redistributions of source code must retain the above copyright notice, this
 *    list of conditions and the following disclaimer.
 *  * Redistributions in binary form must reproduce the above copyright notice,
 *    this list of conditions and the following disclaimer in the documentation
 *    and/or other materials provided with the distribution.
 *  * Neither the name of the copyright holder nor the names of its
 *    contributors may be used to endorse or promote products derived from
 *    this software without specific prior written permission.
 *  THIS SOFTWARE IS PROVIDED BY THE COPYRIGHT HOLDERS AND CONTRIBUTORS "AS IS"
 *  AND ANY EXPRESS OR IMPLIED WARRANTIES, INCLUDING, BUT NOT LIMITED TO, THE
 *  IMPLIED WARRANTIES OF MERCHANTABILITY AND FITNESS FOR A PARTICULAR PURPOSE ARE
 *  DISCLAIMED. IN NO EVENT SHALL THE COPYRIGHT HOLDER OR CONTRIBUTORS BE LIABLE
 *  FOR ANY DIRECT, INDIRECT, INCIDENTAL, SPECIAL, EXEMPLARY, OR CONSEQUENTIAL
 *  DAMAGES (INCLUDING, BUT NOT LIMITED TO, PROCUREMENT OF SUBSTITUTE GOODS OR
 *  SERVICES; LOSS OF USE, DATA, OR PROFITS; OR BUSINESS INTERRUPTION) HOWEVER
 *  CAUSED AND ON ANY THEORY OF LIABILITY, WHETHER IN CONTRACT, STRICT LIABILITY,
 *  OR TORT (INCLUDING NEGLIGENCE OR OTHERWISE) ARISING IN ANY WAY OUT OF THE USE
 *  OF THIS SOFTWARE, EVEN IF ADVISED OF THE POSSIBILITY OF SUCH DAMAGE.
 //*/

#include "nts1_iface.h"

#include <assert.h>

#include "stm32f0xx_hal.h"
#include "stm32f0xx_hal_def.h"
#include "stm32f0xx_hal_spi.h"

#include "stm32_def.h"
#include "PeripheralPins.h"
#include "PinAF_STM32F1.h"
#include "pinconfig.h"
#include "spi_com.h"

#define SPI_PERIPH       SPI2
#define SPI_MISO_PORT    GPIOB
#define SPI_MISO_PIN     GPIO_PIN_14
#define SPI_MOSI_PORT    GPIOB
#define SPI_MOSI_PIN     GPIO_PIN_15
#define SPI_SCK_PORT     GPIOB
#define SPI_SCK_PIN      GPIO_PIN_13
#define SPI_GPIO_AF      GPIO_AF0_SPI2

#define SPI_IRQn         SPI2_IRQn
#define SPI_IRQ_PRIORITY 1
#define SPI_IRQ_HANDLER  SPI2_IRQHandler

#define SPI_GPIO_CLK_ENA()   __HAL_RCC_GPIOB_CLK_ENABLE()
#define SPI_FORCE_RESET()    __HAL_RCC_SPI2_FORCE_RESET()
#define SPI_RELEASE_RESET()  __HAL_RCC_SPI2_RELEASE_RESET()
#define SPI_CLK_ENABLE()     __HAL_RCC_SPI2_CLK_ENABLE()
#define SPI_CLK_DISABLE()    __HAL_RCC_SPI2_CLK_DISABLE()

#define ACK_PORT         GPIOB
#define ACK_PIN          GPIO_PIN_12

#define ACK_GPIO_CLK_ENABLE() __HAL_RCC_GPIOB_CLK_ENABLE()

#define PANEL_ID_MASK    0x38  // Bits 3-5
#define PANEL_CMD_EMARK  0x40  // Bit  6
#define PANEL_START_BIT  0x80  // Bit  7

#define SPI_TX_BUF_SIZE (0x200)
#define SPI_TX_BUF_MASK (SPI_TX_BUF_SIZE - 1)

#define SPI_RX_BUF_SIZE (0x200 )
#define SPI_RX_BUF_MASK (SPI_RX_BUF_SIZE - 1)

#ifndef true 
#define true 1
#endif

#ifndef false
#define false 0
#endif

// ----------------------------------------------------

enum {
  k_tx_cmd_event = 0x84U,
  k_tx_cmd_param = 0x85U,
  k_tx_cmd_other = 0x86U,
  k_tx_cmd_dummy = 0x87U
};

enum {
  k_tx_subcmd_other_ack      = 0x3U,
  k_tx_subcmd_other_version  = 0x10U,
  k_tx_subcmd_other_bootmode = 0x11U,
};

enum {
  k_rx_cmd_event = 0x84U,
  k_rx_cmd_param = 0x85U,
  k_rx_cmd_other = 0x86U,
  k_rx_cmd_dummy = 0x87U
};

enum {
  k_rx_subcmd_other_panelid = 0x0U,
  k_rx_subcmd_other_stsreq  = 0x1U,
  k_rx_subcmd_other_ackreq  = 0x3U,
};

typedef struct __nts1_cmd_header {
  uint8_t cmd:3;
  uint8_t panel_id:3;
  uint8_t end_mark:1;
  uint8_t start_bit:1;
} __nts1_cmd_header_t;

// ----------------------------------------------------

static SPI_HandleTypeDef s_spi;

static uint8_t  s_panel_id = PANEL_ID_MASK; // Bits 3-5 "ppp"="111"
static uint8_t  s_dummy_tx_cmd = (PANEL_ID_MASK + 0xC7); // B'11ppp111;

static uint8_t  s_started;

static uint8_t  s_spi_tx_buf[SPI_TX_BUF_SIZE];
static uint16_t s_spi_tx_ridx;  // Read  Index (from s_spi_tx_buf)
static uint16_t s_spi_tx_widx;  // Write Index (to s_spi_tx_buf)

static uint8_t  s_spi_rx_buf[SPI_RX_BUF_SIZE];
static uint16_t s_spi_rx_ridx;  // Read  Index (from s_spi_rx_buf)
static uint16_t s_spi_rx_widx;  // Write Index (to s_spi_rx_buf)

static uint8_t  s_panel_rx_status;
static uint8_t  s_panel_rx_data_cnt;
static uint8_t  s_panel_rx_data[127];

// ----------------------------------------------------

#define SPI_TX_BUF_RESET() (s_spi_tx_ridx = s_spi_tx_widx = 0)
#define SPI_TX_BUF_EMPTY() ((SPI_TX_BUF_MASK & s_spi_tx_ridx) == (SPI_TX_BUF_MASK & s_spi_tx_widx))
#define SPI_RX_BUF_RESET() (s_spi_rx_ridx = s_spi_rx_widx = 0)
#define SPI_RX_BUF_EMPTY() ((SPI_RX_BUF_MASK & s_spi_rx_ridx) == (SPI_RX_BUF_MASK & s_spi_rx_widx))

#define SPI_BUF_INC(idx, bufSize) (((idx+1) == bufSize) ? 0 : idx + 1)

// ----------------------------------------------------

static inline void s_port_startup_ack(void)
{
  ACK_PORT->BSRR = ACK_PIN;
}

static inline void s_port_wait_ack(void)
{
  ACK_PORT->BRR = ACK_PIN;
}

// ----------------------------------------------------

static inline void s_spi_raw_fifo_push8(SPI_TypeDef* SPIx, uint8_t data)
{
  const uint32_t spix_dr = (uint32_t)SPIx + 0x0C;
  *(__IO uint8_t *) spix_dr = data;
}

static inline uint8_t s_spi_raw_fifo_pop8(SPI_TypeDef* SPIx)
{
  const uint32_t spix_dr = (uint32_t)SPIx + 0x0C;   
  return *(__IO uint8_t *) spix_dr;
}

static uint8_t s_spi_chk_rx_buf_space(uint16_t size)
{
  uint16_t count;

  if (s_spi_rx_ridx <= s_spi_rx_widx) {
    count = (SPI_RX_BUF_SIZE + s_spi_rx_ridx) - s_spi_rx_widx;
  } else {
    count = s_spi_rx_ridx - s_spi_rx_widx;
  }
  return (count > size);
}

static uint8_t s_spi_rx_buf_write(uint8_t data) 
{
  uint16_t bufdatacount;
  if (s_spi_rx_ridx <= s_spi_rx_widx) {
    bufdatacount = s_spi_rx_widx - s_spi_rx_ridx;
  } else {
    bufdatacount = SPI_RX_BUF_SIZE + s_spi_rx_widx - s_spi_rx_ridx;
  }
  if (bufdatacount < (SPI_RX_BUF_SIZE - 2)) {
    s_spi_rx_buf[SPI_RX_BUF_MASK & s_spi_rx_widx] = data;
    s_spi_rx_widx = SPI_BUF_INC(s_spi_rx_widx, SPI_RX_BUF_SIZE);
    return true;
  }
  return false;
}

static uint8_t s_spi_rx_buf_read(void)
{
  const uint8_t data = s_spi_rx_buf[SPI_RX_BUF_MASK & s_spi_rx_ridx];
  s_spi_rx_ridx = SPI_BUF_INC(s_spi_rx_ridx, SPI_RX_BUF_SIZE);
  return data;
}

static uint8_t s_spi_chk_tx_buf_space(uint16_t size)
{
  uint16_t count;
  if (s_spi_tx_ridx <= s_spi_tx_widx) {
    count = SPI_TX_BUF_SIZE + s_spi_tx_ridx - s_spi_tx_widx;
  } else {
    count = s_spi_tx_ridx - s_spi_tx_widx;
  }
  return (count > size);
}
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

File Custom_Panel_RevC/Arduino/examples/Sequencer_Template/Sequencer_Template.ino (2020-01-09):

/* 
   Sequencer Template for NTS-1 Custom Panel reference board rev.B
     
   BSD 3-Clause License
    Copyright (c) 2020, KORG INC.
    All rights reserved.
    Redistribution and use in source and binary forms, with or without
    modification, are permitted provided that the following conditions are met:
   * Redistributions of source code must retain the above copyright notice, this
      list of conditions and the following disclaimer.
    * Redistributions in binary form must reproduce the above copyright notice,
      this list of conditions and the following disclaimer in the documentation
      and/or other materials provided with the distribution.
    * Neither the name of the copyright holder nor the names of its
      contributors may be used to endorse or promote products derived from
      this software without specific prior written permission.
    THIS SOFTWARE IS PROVIDED BY THE COPYRIGHT HOLDERS AND CONTRIBUTORS "AS IS"
    AND ANY EXPRESS OR IMPLIED WARRANTIES, INCLUDING, BUT NOT LIMITED TO, THE
    IMPLIED WARRANTIES OF MERCHANTABILITY AND FITNESS FOR A PARTICULAR PURPOSE ARE
    DISCLAIMED. IN NO EVENT SHALL THE COPYRIGHT HOLDER OR CONTRIBUTORS BE LIABLE
    FOR ANY DIRECT, INDIRECT, INCIDENTAL, SPECIAL, EXEMPLARY, OR CONSEQUENTIAL
    DAMAGES (INCLUDING, BUT NOT LIMITED TO, PROCUREMENT OF SUBSTITUTE GOODS OR
    SERVICES; LOSS OF USE, DATA, OR PROFITS; OR BUSINESS INTERRUPTION) HOWEVER
    CAUSED AND ON ANY THEORY OF LIABILITY, WHETHER IN CONTRACT, STRICT LIABILITY,
    OR TORT (INCLUDING NEGLIGENCE OR OTHERWISE) ARISING IN ANY WAY OUT OF THE USE
    OF THIS SOFTWARE, EVEN IF ADVISED OF THE POSSIBILITY OF SUCH DAMAGE.
//*/
 
// --- NTS-1 main boardinterface ------------------------------------------------------------------
#include <nts1.h>

NTS1 nts1;

// --- UI definitions and state -------------------------------------------------------------------
enum { sw_1 = 0, sw_2, sw_3, sw_4, sw_5, sw_6, sw_7, sw_8, sw_9, sw_10, sw_count };
const uint8_t g_sw_pins[sw_count] = { D34, D35, D36, D37, D38, D40, D41, D42, D46, D47};

enum {
  sw_step1 = sw_1,
  sw_step2 = sw_2,
  sw_step3 = sw_3,
  sw_step4 = sw_4,
  sw_step5 = sw_5,
  sw_step6 = sw_6,
  sw_step7 = sw_7,
  sw_step8 = sw_8,
  sw_play = sw_9,
  sw_shift = sw_10,
};

enum { led_1 = 0, led_2, led_3, led_4, led_5, led_6, led_7, led_8, led_count };
const uint8_t g_led_pins[led_count] = { D16, D17, D18, D19, D22, D23, D24, D25 };

enum { vr_1 = 0, vr_count };
const uint8_t g_vr_pins[vr_count] = { A10 };

typedef struct {
  HardwareTimer *timer; // for switch/vr scan
  uint32_t steps_pressed;
  bool is_shift_pressed;
} ui_state_t;

ui_state_t g_ui_state = {
  .timer = NULL,
  .steps_pressed = 0x0,
  .is_shift_pressed = false
};

// --- Sequencer definitions and state -----------------------------------------------------------

#define k_seq_length 8
#define k_seq_ticks_per_step 100

enum {
  k_seq_flag_reset = 1U<<0
};

typedef struct {
  HardwareTimer *timer; // for seq ticks
  uint32_t last_tick_us;
  uint8_t ticks;
  uint8_t step;
  uint8_t note;
  uint8_t flags;
  uint32_t gates;
  uint32_t tempo;
  uint8_t notes[k_seq_length];
  bool is_playing;
} seq_state_t;

seq_state_t g_seq_state = {
  .timer = NULL,
  .last_tick_us = 0,
  .ticks = 0xFF, // invalid
  .step = 0xFF, // invalid
  .note = 0xFF, // invalid
  .flags = 0x00, // none
  .gates = 0xFF, // 1 bit per step, all on
  .tempo = 1200, // 120.0 x 10
  .notes = {
    0x42, 0x42, 0x42, 0x42, 0x42, 0x42, 0x42, 0x42
  },
  .is_playing = false
};

// --- UI scan/control ------------------------------------------------------------------------

void set_step_leds(uint8_t mask) {
  for (uint8_t i=led_1; i<=led_8; ++i) {
    nts1_digital_write(g_led_pins[i], (mask & (1U<<i)) ? HIGH : LOW);
  }
}

void scan_switches(unsigned long now_us) {
  static uint32_t last_sw_sample_us = 0;
  static uint32_t last_sw_state = 0;
  static uint8_t sw_chatter_cnt[sw_count] = {0};
  uint32_t sw_events = 0;
  
  if (now_us - last_sw_sample_us > 1000) {
    uint32_t sw_state = 0;
    for (uint8_t i=0; i<sw_count; ++i) 
    {
      const uint32_t val = nts1_digital_read(g_sw_pins[i]);
      const uint32_t last_val = ((last_sw_state>>i)&0x1);
      if (val != last_val) {
        if (++sw_chatter_cnt[i] > 6) {
          sw_state |= val<<i;
          sw_chatter_cnt[i] = 0;
        }
        else {
          sw_state |= last_val<<i;
        }
      }
      else {
        sw_chatter_cnt[i] = 0;
        sw_state |= last_val<<i;
      }
    }
    
    if (last_sw_state != sw_state) {
      // Change detected
       
      sw_events = sw_state ^ last_sw_state;
      
      // Check for play switch event
      static const uint32_t k_play_sw_mask = (1U<<sw_play);
      if (sw_events & k_play_sw_mask) {
         if ((~sw_state) & k_play_sw_mask) {
            // Pressed down
            // - reset sequencer
            g_seq_state.flags |= k_seq_flag_reset;
            // - toggle play state
            g_seq_state.is_playing = !g_seq_state.is_playing;
         }
      }

      // Check for shift switch event
      static const uint32_t k_shift_sw_mask = (1U<<sw_shift);
      if (sw_events & k_shift_sw_mask) {
        g_ui_state.is_shift_pressed = (sw_state & k_shift_sw_mask) == 0; // active low
      }

      // Check for step switch events
      static const uint32_t k_step_sw_mask = ((1U<<sw_9)-1);
      const uint32_t step_sw_events = sw_events & k_step_sw_mask;
      if (step_sw_events) {
        // New step presses
        const uint32_t new_presses = (~sw_state) & step_sw_events;
        // Released steps
        const uint32_t released = sw_state & step_sw_events;

        if (g_ui_state.is_shift_pressed) {
          // Set/unset sequencer gates
          g_seq_state.gates ^= new_presses>>sw_step1;
          set_step_leds(g_seq_state.gates);
        }
        
        g_ui_state.steps_pressed |= new_presses;
        g_ui_state.steps_pressed &= ~(released);
      }
    }

    last_sw_state = sw_state; // save state for ref. on next cycle
    last_sw_sample_us = now_us;
  }
}

void handle_vr_1(int16_t value) {
  // Keep references for catch mode behavior
  static int32_t last_tempo_vr_val = 0xFFFFFFFF;
  static int32_t last_shape_vr_val = 0xFFFFFFFF;
  
  if (g_ui_state.steps_pressed) { 
    // Set note if steps are pressed
    uint8_t note = value>>3; // 10bit to 7bit
    for (uint8_t i=sw_step1; i<=sw_step8; ++i) {
      if (g_ui_state.steps_pressed & (1U<<i)) {
         g_seq_state.notes[i] = note;
         if (note == 0) {
           // Force gate off
           g_seq_state.gates &= ~(1U<<i);
           nts1_digital_write(g_led_pins[i], LOW);
         }
         else {
           // Force gate on
           g_seq_state.gates |= 1U<<i;
           nts1_digital_write(g_led_pins[i], HIGH);
         }
      }
    }
  }
  else if (g_ui_state.is_shift_pressed){
    // Change tempo when shift is pressed
    if(last_tempo_vr_val == 0xFFFFFFFF
       || (abs(value - last_tempo_vr_val) < 10)) {
      g_seq_state.tempo = 200 + (value>>1)*10 + (value&0x1)*5; // 20.0 - 531.5 BPM in 0.5 increments
      last_tempo_vr_val = value;
    }
  }
  else {
    // Change SHAPE by default
    if(last_tempo_vr_val == 0xFFFFFFFF
       || (abs(value - last_shape_vr_val) < 10)) {
      // Set SHAPE parameter on NTS-1 main board
      nts1.paramChange(k_param_id_osc_shape, k_invalid_param_sub_id, value);
      last_shape_vr_val = value;
    }
  }
}

void scan_vrs(unsigned long now_us) {
  static uint32_t last_vr_sample_us = 0;
  static uint32_t last_vr_states[vr_count] = {0};
  static uint8_t vr_chatter_cnt[vr_count] = {0};
  
  if (now_us - last_vr_sample_us > 1000) {
    for (uint8_t i=0; i<vr_count; ++i) 
    {
      int32_t vr_state = 0;
      const int32_t val = analogRead(g_vr_pins[i]);
      const int32_t last_val = last_vr_states[i];
      if (val != last_val) {
        if (++vr_chatter_cnt[i] > 4) {
          vr_state = val;
          vr_chatter_cnt[i] = 0;
        }
        else {
          vr_state = last_val;
        }
      }
      else {
        vr_chatter_cnt[i] = 0;
        vr_state = last_val;
      }

      if (last_val == vr_state) {
        last_vr_sample_us = now_us;
        continue;
      }

      switch (i) {
        case vr_1:
          handle_vr_1(vr_state & 0x3FF);
          break;
        default:
          break;  
      }
      
      last_vr_states[i] = vr_state;
    }
    
    last_vr_sample_us = now_us;
  }
}

void scan_interrupt_handler(HardwareTimer *t) {
  unsigned long now_us = micros();
  scan_switches(now_us);
  scan_vrs(now_us);
}

// --- Sequencer Runtime ------------------------------------------------------------------------

void seq_interrupt_handler(HardwareTimer *t) {
  uint32_t now_us = micros();
  
  if (g_seq_state.flags & k_seq_flag_reset) {
    if (g_seq_state.note != 0xFF) {
      // There's a pending note on
      // Send note off event to NTS-1 main board
      nts1.noteOff(g_seq_state.note);
      const uint32_t cur_step = g_seq_state.step;
      const uint8_t highlow = (g_seq_state.gates & (1U<<cur_step)) ? HIGH : LOW; // revert LEDs
      nts1_digital_write(g_led_pins[cur_step], highlow);
    }
    // reset sequencer
    g_seq_state.ticks = 0xFF;
    g_seq_state.step = 0xFF;
    g_seq_state.note = 0xFF;
    g_seq_state.last_tick_us = now_us;
    g_seq_state.flags &= ~k_seq_flag_reset; // clear flags
  }

  if (!g_seq_state.is_playing) {
    return;
  }
  
  const uint32_t us_per_tick = 600000000UL/(4*g_seq_state.tempo*100);
  const uint32_t tick_delta_us = now_us - g_seq_state.last_tick_us;
  if (tick_delta_us < us_per_tick) {
    return; 
  }
  // Increment ticks
  ++g_seq_state.ticks;
  
  // Set adjusted reference time for next tick
  g_seq_state.last_tick_us = now_us - (tick_delta_us - us_per_tick);

  uint32_t cur_step = g_seq_state.step;

  if (g_seq_state.ticks >= k_seq_ticks_per_step) {
    cur_step = (cur_step + 1) % k_seq_length;
    g_seq_state.ticks = 0;
    
    const uint8_t note = g_seq_state.notes[cur_step];
    
    if (g_seq_state.gates & (1U<<cur_step)) {
      // Send note on event to NTS-1 main board
      nts1.noteOn(note, 0x7F);
      nts1_digital_write(g_led_pins[cur_step], LOW);
    }
    else {
      nts1_digital_write(g_led_pins[cur_step], HIGH);
    }
    
    g_seq_state.step = cur_step;
    g_seq_state.note = note;
  }
  else if (g_seq_state.ticks >= (k_seq_ticks_per_step>>1)) {
    if (g_seq_state.note != 0xFF) {
      // Send note off event to NTS-1 main board
      nts1.noteOff(g_seq_state.note);
      uint32_t cur_step = g_seq_state.step;
      const uint8_t highlow = (g_seq_state.gates & (1U<<cur_step)) ? HIGH : LOW; // revert LEDs
      nts1_digital_write(g_led_pins[cur_step], highlow);
      g_seq_state.note = 0xFF;
    }
  }
}

// --- Hardware Timer Setup ------------------------------------------------------------------------

HardwareTimer *setup_timer(uint8_t ref_pin, uint32_t prescaler, uint32_t overflw, void (*interrupt_handler)(HardwareTimer *)) {
  // Automatically retrieve TIM instance and channel associated to pin
  // This is used to be compatible with all STM32 series automatically.
  HardwareTimer *timer = new HardwareTimer((TIM_TypeDef *)pinmap_peripheral(digitalPinToPinName(ref_pin), PinMap_PWM));
  uint32_t channel = STM_PIN_CHANNEL(pinmap_function(digitalPinToPinName(ref_pin), PinMap_PWM));
  timer->setMode(channel, TIMER_OUTPUT_COMPARE);
  
  // With a PrescalerFactor = 1, the minimum frequency value to measure is : TIM counter clock / CCR MAX
  //  = (SystemCoreClock) / 65535
  // Example on Nucleo_L476RG with systemClock at 80MHz, the minimum frequency is around 1,2 khz
  // To reduce minimum frequency, it is possible to increase prescaler. But this is at a cost of precision.
  // The maximum frequency depends on processing of the interruption and thus depend on board used
  // Example on Nucleo_L476RG with systemClock at 80MHz the interruption processing is around 4,5 microseconds and thus Max frequency is around 220kHz
  const uint32_t PrescalerFactor = 4;
  timer->setPrescaleFactor(PrescalerFactor);
  timer->setOverflow(overflw); //0x10000); // Max Period value to have the largest possible time to detect rising edge and avoid timer rollover
  timer->attachInterrupt(channel, interrupt_handler);
  //uint32_t freq = timer->getTimerClkFreq() / timer->getPrescaleFactor();
  return timer;
}

// --- Arduino Sketch Entry ------------------------------------------------------------------------

void setup() {
  // - Setup debug serial if needed ------------------------------
  Serial.begin(115200);

  // - Initialize VR and LED GPIOS -------------------------------
  for (uint8_t i=0; i<sw_count; ++i) {
    pinMode(g_sw_pins[i], INPUT_PULLUP);
  }
  for (uint8_t i=0; i<led_count; ++i) {
    uint8_t led_pin=g_led_pins[i];
    pinMode(led_pin, OUTPUT);
  }
  
  // - Initialize NTS-1 main board interface ---------------------
  nts1.init();

  // - Initialize UI state ---------------------------------------
  set_step_leds(g_seq_state.gates);
  
  // - Setup Hardware Timer for switch/vr scanning ---------------
  g_ui_state.timer = setup_timer(D2, 24, 2000, scan_interrupt_handler);

  // - Setup Hardware Timer for sequencer ------------------------
  g_seq_state.timer = setup_timer(D4, 24, 1000, seq_interrupt_handler); // 2KHz interrupt? -> 500ns per cycle

  // - Start timers ----------------------------------------------
  g_ui_state.timer->resume();
  g_seq_state.timer->resume();
}

// --- Arduino Sketch Idle Loop ----------------------------------------------------------------------

void loop() {  
  unsigned long now_ms = millis();
  unsigned long now_us = micros();
  
  // - Run NTS-1 interface idle callback -------------------------
  nts1.idle();
}

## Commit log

2020-01-08 Add hardware files.
    [BOM-mouser.xls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]
2020-01-08 Add PDF version of BOM.
2020-01-09 [revB][arduino] Add example template Sketches.
2020-01-09 Add READMEs to arduino templates.
2020-01-09 [revB] Remove japanese column name from BOM, re-export PDF with all columns.
    [BOM-mouser.xls]
2020-01-09 [revB] Add gerber reference and mount diagram PDFs.
2020-01-10 Rev.B data was actually Rev.C, fix some conflicting info in KiCAD files.
    [BOM-mouser.xls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]
2020-01-10 Add Arduino boards index file.
2020-01-10 Fix wrong size of board package.
2020-01-10 Rename Arduino boards index file to common format.
2020-01-10 Rename arduino board platform.
2020-01-10 Revert name of arduino board platform.
2020-01-10 Update Arduino board package url, hash and size.
2020-01-10 Update Arduino board package website URL and online help URL
2020-01-10 Fix Arduino board online help URL
2020-01-10 Update Arduino board hash and size.
2020-01-10 Change packager for tools in order to remove dependency on STM32 package.
2020-01-10 [revC] Replace examples with full NTS-1 board library.
2020-01-13 [revC] Lower power stabilizing capacitor to 1u.
    [BOM-mouser.xls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]
2020-01-15 [revC][arduino] Add more details to NTS1 class definition doc.
2020-01-15 [revC][arduino] Add type definitions for rx message handlers and remove extraneous colons.
2020-02-14 [revC][arduino] Fix param sub-id syntax.
2020-02-14 [revC][arduino] Add nts1_iface.h/.c from board variant for reference.
2020-02-14 [arduino] Update arduino package index JSON: add v1.0.1 package.
2020-02-14 [revC][arduino] Update NTS1 class reference with changes for v1.0.1
2020-02-14 [revC][arduino] Fix format for some params.
2020-02-14 [arduino] Fix URL for 1.0.1 package indedx.
2020-02-14 [revC][arduino] Fix include in code example to match v1.0.1.
